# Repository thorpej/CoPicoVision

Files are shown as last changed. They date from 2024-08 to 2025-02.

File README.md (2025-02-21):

# CoPicoVision - A ColecoVision clone using a Raspberry Pi Pico with pico9918 for video
The CoPicoVision stems from yet another bout of nostalgia for a time before
photorealistic video games, when all we had was blocky tile graphics and a
few bleeps and bloops and gosh darn it, we liked it!  When I was a kid, I got
a ColecoVision one Christmas and I played the h*ll out of it.  Alas, I no
longer have it, but I wish I still did, and building a clone seems a lot more
fun than over-paying for one on eBay.

Ok, fine, I have a second motive: It also serves as a test mule for using
modified variants of Troy Schrapel's excellent
[pico9918](https://github.com/visrealm/pico9918) project, something I'm
considering using in other projects, and test mules that can play Mr. Do!
and Zaxxon (yes, yes, yes, and Donkey Kong) are the best kinds of test mules.

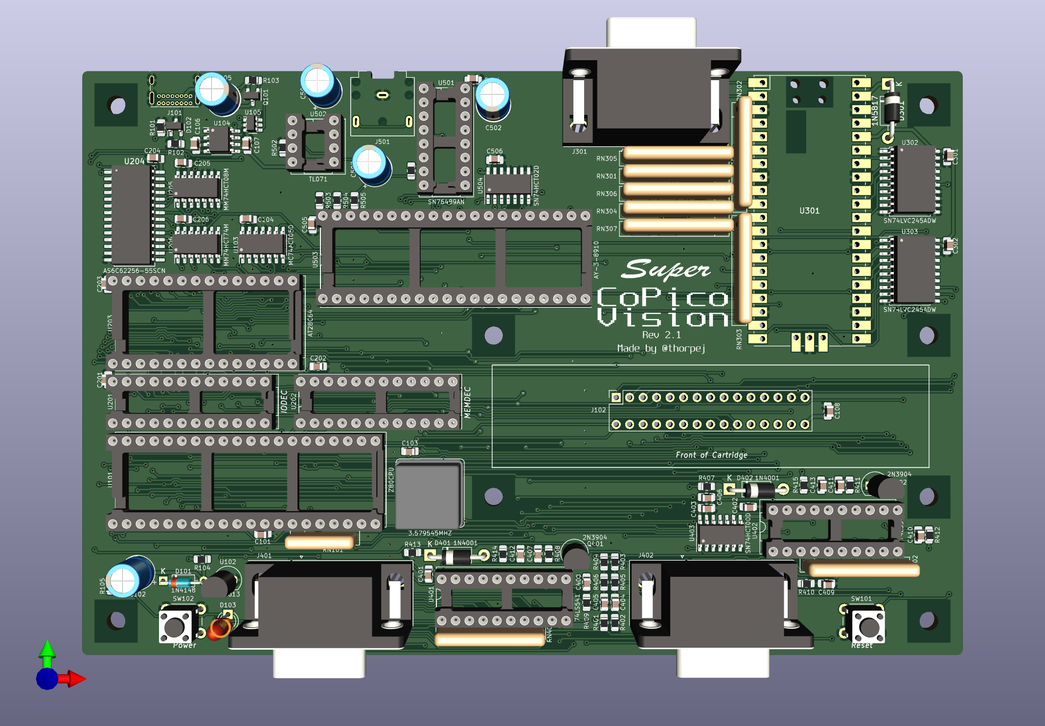
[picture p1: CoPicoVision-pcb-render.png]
3D render of board image


This work is licensed under the [Creative Commons Attribution
ShareAlike 4.0 International license](https://creativecommons.org/licenses/by-sa/4.0/).



## Project Status
### Update - Feb 21, 2025
I've had some time recently to test my one built-up rev 2.0 board (with
all of the necessary rework performed).  I found that one rework procedure
was incomplete, and therefore I'm recommending that others do not build up
any 2.x boards at this time.  I managed to spot the problem and avoided
damaging any chips, but I'd rather be safe than sorry.  I also discovered
another bug, of sorts, in the memory decoding logic when testing an SGM
game ("1942").  Spoiler alert: SGM games are not working correctly yet.
The issue revolves around the way address lines A10-A12 are gated to
provide the stock ColecoVision RAM "mirroring" behavior.  Those lines are
gated too aggressively, and a change to the MEMDEC GAL and a change to
the input signal to the 74HCT08 that gates those lines was required.  I
discovered this using a memory map test utility I wrote for this purpose.
I still don't understand how this bug would break "1942", though, so I
still have some work to do.

### Update - Jan 23, 2025
I received the rev 2.0 boards a little while ago, and the other night started
building one up, only to realize I forgot to oder some parts.  Oh well,
no big deal... I have some travel planned for the next few days, and when
I get back, the parts will be here.  I'm continuing to make tweaks to the
rev 3.0 board, replacing through-hole components with surface-mount
equivalents; it's really amazing how much faster it is to build up a
board with surface-mount bits.  The rev 2.0 CoPicoVision is by far my
most ambitious SMT project to date, and rev 3.0 will be even MOAR.

I've settled on rev 3.0 being the final "classic" CoPicoVision (barring
bugs, obviously), but I am already thinking about a rev 4.0 that will
eliminate the out-of-production audio chips in favor of a second Pi Pico
that will emulate both the SN76489AN and the AY-3-8910.  I'm going to
spend a lot of time breadboarding that before I make the leap, but it's
my goal to eliminate those hard to source parts.  Only the Z80A will remain,
and it's still somewhat available (for now, at least).

### Update - Jan 7, 2025
I've done some work to update to the latest version of pico9918, and
submitted a PR for my build parameterization changes.

### Update - Dec 31, 2024
Ok, I am tagging rev 2.1 that contains the MEMDEC fix and has a rework
procedure involving an interposer board for the AY-3-8910 clock issue.
I don't plan to actually spin any of these boards myself, but it's a
checkpoint (and I am spinning a run of interposers).

Happy New Year, everyone!

### Update - Dec 30, 2024
Aaaaand I've realized I made another error, this time in the SGM extended
memory support.  Specifically, when disabling the BIOS ROM.  I foolishly
used /WR as an input signal to the decoder, completely forgetting the
fact that the Z80 memory cycle timings are very different from the I/O
cycle timings.  To fix this, I'm going to need to change the MEMDEC GAL
inputs and equations (it should take /RD as an input rather than /WR).
I will post a re-work for the rev 2.0 boards (it will involve cutting a
trace and running a short bodge wire between the Z80 and the MEMDEC GAL).

### Update - Dec 29, 2024
I've realized that I made a major error in the clock frequency for the
AY-3-8910, and this is going to require me to spin the board.  Basically,
I used the CPUCLK as the input to the AY-3-8910, when it actually needs
to be divided by 2.  I can do that by adding a D-FF.  I'll make an
interposer board for rev 2.0 systems that sits between the AY-3-8910
and the main board that carries the FF chip.  If that works out OK,
I'll just probably put that down on the main board in rev 3.0, rather
than overhauling the whole clock circuit.

### Update - Dec 21, 2024
Ok, I think I'm going to tag a 2.0 pre-release and get the boards off to
fabrication.  I don't really anticipate making any more board changes in
the short term -- just hanges to ancillary documents.  So stay tuned for
that!

### Update - Dec 19, 2024
Well, I had some time to kill on a plane, so I started the process to
claw back board real estate in order to fit the additional components
needed for "Super CoPicoVision".  But of course, once the initial shrink
was done, I needed to know where the additional components would fit before
I re-routed the board.  This of course meant that I needed to actually
add these additional components to the board, meaning that I needed to do
the work to add them to the schematic.  Anyway, you can probably guess
where this is going!  I need to now fix up the BOM (when you're ordering
ICs in surface-mount packages, you need to be a little more specific about
which part number you order!)

### Update - Dec 15, 2024
I had to take a break from CoPicoVision for a little while for various
reasons, but I'm trying to get back to it.  After mulling it over and
thinking about future "Super CoPicoVision" plans, I decided to change the
audio output buffer to a TL071 opamp, taking advantage of the -5V rail I
have at my disposal.  I added an LTspice simulation of the circuit, including
passively mixing in the output of an AY-3-8910, which would be present on
this hypothetical "Super CoPicoVision".  I want to get this send off to the
fab soon and if everthing is fine, call this version "CoPicoVision 1.0".

I do plan to keep working on it, though!  I plan on experimenting with
the layout, switching to SMT components as necessary, to see if I can fit
the extra chips needed for the Super flavor within the same board footprint.

### Update - Nov 10, 2024
I finally got a chance to get set up with some powered speakers (with a
volume control) to get a better sense of how the audio section behaves.
With the AudioEngine 2+ speakers I tested with, the noise isn't really
that bad at all, and it definitely seems to be a property of the SN76489AN
(placing my finger on top of the chip while running makes an audible
different in the noise profile).

I haven't yet bodged the audio section changes in revision 0.2 onto this
revision 0.1 board.  I really should try to do that soon and re-evaluate.

### Update - Oct 12, 2024
I've updated the schematic and PCB to fix the swapped controller bug in
the rev 0.1 boards, and bumped the revision to 0.2.

I've also built up the audio section of the board and confirmed that it
works.  It's not ideal, though:
* The footprint for the resistor in the emitter-follower is wrong, so even
the relatively-small 1/2 watt resistor I spec'd doesn't quite fit.
* I should have put a current-limiting resistor between the SN76489AN and
the emitter-follower.  It works as it is, but the current setup has the
SN76489AN sourcing more current than it really ought to.  (Maybe I should
have just used a 2N7000 in a source-follower configuration instead?)
* The output is pretty noisy.  It's not _distorted_, but there's hiss and
other audio artifacts.  I remember the original ColecoVision being this
way, but always assumed it was the fault of the RF modulator.  I may bodge
in a passive low-pass filter to cut down on the noise.

### Update - Oct 11, 2024
Built up the controller section and played some Donkey Kong!  I did make
a mistake on the controller section, however.  Controller 1 and 2 are
swapped.  I will correct this in the next revision of the board, and there
is a [procedure](errata/rev0_1_controller_bodge.md) to fix the rev 0.1 boards
that I've already run off.

There also a mistake in the physical placement of the card edge connector
for the cartridge.  It's a few millimeters too close to the front of the
board, and so the cartridge bumps into one of the 2N3904s in the controller
circuit and the cartridge doesn't quite align with the silk screen outline.
That's going to be a little tricker to fix because I might have to re-route
some of the board, but I'll fix that up as well.

Guess I should build the audio section next!

### Update - Oct 10, 2024
After replacing a bad oscillator, the first test board is working!  I have
not yet installed the audio or controller circuitry yet, but I can boot up
Donkey Kong and Buck Rogers, and, due to the lack of controller circuitry
being misinterpreted as input, game play starts!

### Update - Sept 24, 2024
Boards have been back for a while now, and I finally got around to starting
to build one up.  Thought I had all of the resistors I needed in my inventory,
but alas, I did not, so need to place a Jameco order!

### Update - Sept 2, 2024
I made some small adjustments to the PCB, and sent rev 0.1 off for
fabrication!

### Update - Sept 1, 2024
I made forks of pico9918 and vrEmuTms9918 in order to make the changes
needed for CoPicoVision, and then went ahead and made all of those
changes.  Initial firmware version checked in!

### Initial - Aug 31, 2024
The initial "rev 0.1" hardware design is done and ready to send off for
fabrication.  There is some software work to do on the pico9918 side of
things, but the changes I have in mind are trivial.  My plan is to wrap
my changes in proper configuration options and feed those changes back
to Troy.

So, yah, it's early!  Watch this space!

## Design philosophy
My initial goal was to play ColecoVision games (and subsequently, also
games that require the Super Game Module), not to produce a faithful
clone of the circuit.  It needs to be fully-compatible with ColecoVision
and SGM games, but that's the extent of it.  As such, some shortcuts are
going to be taken.

First of all, I'm using Troy Schrapel's excellent pico9918 engine for the video
display.  This reduces the number of vintage parts that need to be sourced, and
gives me VGA video output.  I won't be using the pico9918 as-is, however; since
I don't need all of the outputs of a real TMS9918A (no CPUCLK or GROMCLK), I'm
using a modified pico9918 firmware that doesn't bother with those outputs and
thus allows me to use a regular Raspberry Pi Pico as a module.

Second of all, I'm not going to bother with the expansion interface; I don't
particularly care about connecting an Adam module, and if I ever do, then it
will be time to re-evaluate my life choices.

And lastly, as should be obvious through my use of a microcontroller that's
hundreds of times more powerful than the ColecoVision itself, I have no qualms
about using programmable logic to reduce the part count and generally simplify
the design.  In particular, this means GAL22V10s for address decoding and other
glue logic rather than general-purpuse 7400-series parts.  Atmel still makes
a compatible part, and there are open source tools for programming them, so the
design is still very accessible.

There are three "vintage" parts that are required for the CoPicoVision:
* A 4MHz-capable Z80 CPU in a DIP-40 package.
* A TI SN76489AN sound chip.
* A General Instrument AY-3-8910 sound chip (a Yamaha YM2149 will probably
  also work, but I don't have any to try).  This is only needed if you want
  to be able to play SGM games; regular ColecoVision games will work without
  it.

Eventually, I'd like to replace the SN76489AN and AY-3-8910s with emulated
parts, (almost certainly using a Pi Pico), but for now the real thing needs
to be sourced.

Obviously, with the Z80 now being EOL'd, that poses a bit of a snag.  Luckily,
I have a stash of modern CMOS Z80s, and this design will also accept a vintage
NMOS Z80.  The CPU is clocked at 3.57MHz, so a Z80A or better is necessary.
Maybe one day I'll evaluate one of the FPGA Z80 cores floating around
to see if it's feasible to use one of those with an iCE40 FPGA in an updated
version of the CoPicoVision.  But for now, a genuine Z80 must be used.

## Design details
I spent some time mulling over how I wanted to approach this board.  I
considered doing an all-SMT board (except for the stuff that was only
available as through-hole), but for the first version of the board I
ultimately went with mostly through-hole parts (except for the power supply)
in order to try and keep a more retro look.

This wasn't feasible for version 2, the "Super CoPicoVision"; I wanted to
keep the same basic envelope, so I had no choice to shrink the components
in order to make space for the additional logic chips and the large DIP-40
AY-3-8910.  So, I converted all of the individual resistors and ceramic
capacitors to 0805 packages, and the RAM and most logic ICs to SOIC packages
(I left the 74LS541s in the controller input section as DIP packages).

The board is 4 layers: signals (and ground fill) top and bottom, along with
an internal ground plane and power plane.  I arrived at the size of the board
through experimentation; essentially, I did a rough layout of the board into
what I thought "looked pretty good", placed mounting holes and keep-outs, and
then drew an edge-cut box around it.  Once the box was drawn, I tried to stay
within that envelope.  I'm a total novice when I comes to PCB layout and
design, and I routed the entire board by hand, but did manage to make it fit.
Some signals are routed, ahem, interestingly, but this isn't a high-speed
design so it should be just fine.

The font of the board has power and reset buttons and the 2 controller
ports.  The rear of the board has power, audio, and VGA jacks, along with
the USB connector for the Raspberry Pi Pico in case there's a need to
update the pico9918 firmware.  There's a diode in between the Pico and
the rest of the board, so it's safe to update the firmware in situ.

I've included a bill of materials with Mouser part numbers for just about
everything, including the jellybean SMT resistors / capacitors in standard
0805 packages; these jellybean parts can be substituted with equivalent stock
you might have on hand, of course, but I included Mouser part numbers for
convenience.  For the DIP chip sockets, you whatever kind you prefer.  For
the push button switches, there are lots of garden-variety 6mm through-hole
momentary push buttons out there, so you whatever you prefer.

### Power supply
The power supply is fairly simple, since we don't need the -12V rail that's
found on the original ColecoVision.  We do, however, require a -5V rail, which
is used as a bias voltage in the controller interface circuit as well as for
the op-amp used as an output buffer in the audio circuit.

Power comes in via a USB-C connector (with ESD protection diodes on the
control channel signals).  Power is switched using a MAX16054 on/off
supervisor chip that controls a high-side P-FET to supply power to the
rest of the system.  The MAX16054 is controlled using a single momentary
pushbutton.

The -5V rail is generated using an ICL7660A charge pump chip.

### Clock and reset generation
On the first revision of the CoPicoVision, the clock circuit was as simple
as it gets: a simply a 3.579545 MHz DIP-8 oscillator can that drove the
whole thing, providing CPUCLK signal to the Z80, the M1 wait-state generator,
and the SN76489AN sound chip.

When the Super Game Module enhancements were added in rev 2.0, this clock
was also provided to the AY-3-8190 sound chip, which was actually a mistake
on my part, and it required an annoying work-around to divide CPUCLK by 2
for the AY-3-8190.

So, in rev 3.0, the clock circuit was completely overhauled to use a
14.31818 MHz oscillator to generate the base clock, which is fed into a
74HCT161 binary counter that is used to divide the base frequency by 4
(CPUCLK - 3.579545 MHz) and 8 (AYCLK - 1.789773 MHz).

The reset circuit is based on the DS1813 reset generator IC, which also
de-bounces the reset button.  There is a small RC network that makes the
power-on-reset slightly longer than a manual reset.

### Address decoding and memory
Address decoding is performed using 2 GAL22V10 programmable logic devices.
The original ColecoVision uses 2 74LS138s for address decoding, but also
requires some extra logic to invert some of the signals used by the decoders.
By using GALs for this purpose, I save the extra logic chips.

The ColecoVision also uses a 74LS74 dual D-type flip-flop along with some
additional logic gates to add a wait-state when the Z80 performs an opcode
fetch.  It does this presumably to give some extra breathing room to slow
ROMs (of the Z80 machine cycles, M1 has the tightest timing).  There is
plenty of space in the MEMDEC GAL for this, so that's where I put it.
There is a large comment in the [MEMDEC GAL](gal-files/memdec.gal) source
file that explains how the wait-state generator works.

The BIOS ROM for the CoPicoVision is contained in a 150ns 28C64 EEPROM.
I chose this part because:
* I had a bunch of them on-hand.
* They're totally fast enough.
* They're still being made and you can buy them new from Mouser and DigiKey.

The CoPicoVision's RAM is an AS6C62256-55SCN, which is a 32KB 55ns SRAM chip.

The ColecoVision's memory address space is divided into 8 8KB "pages":

* $0000 - BIOS ROM
* $2000 - Expansion
* $4000 - Expansion
* $6000 - RAM
* $8000 - Cartridge selector 0
* $A000 - Cartridge selector 1
* $C000 - Cartridge selector 2
* $E000 - Cartridge selector 3

The ColecoVision only has 1KB of RAM at $6000, and the addresses are
incompletely decoded, so that 1KB is mirrored throughout that page.

The Super Game Module has 32KB of extended RAM, only 24KB of which is
available unless the BIOS ROM is diabled.  These features are controlled
by the following two registers:

* Writing 0b00000001 to port $53 enables extended RAM.
* Writing 0b00001101 to port $7F disables the BIOS ROM (0b00001111
  re-enables it).  Games must write one of these two values in order
  to maintain compatability with the Adam.

The CoPicoVision uses a 74HCT74 dual D-type flip-flop to provide these two
control registers (only 2 independently-settable bits are needed).  FF1 is
connected to D0 and provides the XRAMEN signal, and FF2 is connected to D1
and provides the ROMEN signal.  The /RESET line is connected such that FF0
is cleared at reset and FF1 is set at reset.  These two signals are used
by the MEMDEC GAL when decoding memory addresses.  A 74HCT08 quad-AND chip
mixes the XRAM signal with RAM address lines A10-A12, forcing them to 0 when
XRAMEN is disabled and passing them through from the CPU when XRAMEN is
enabled, thus maintaining the RAM mirroring behavior of the original
ColecoVision.

When the ROM is enabled, MEMDEC sends reads from the $0000 page to
the ROM, and when disabled it sends those reads to the RAM.  Writes to
the $0000 page are always sent to RAM.  On the CoPicoVision, the $0000 page
RAM behavior is governed entirely by the ROMEN signal.  I suspect this
doesn't exactly match the original Super Game Module behavior, but I also
suspect that it doesn't matter in any practical sense.

I/O address decoding is handled by the [IODEC GAL](gal-files/iodec.gal).
In the original ColecoVision, I/O addresses were incompletely decoded using
address lines A5-A7:

* $8x writes set controller number pad scan mode
* $Ax reads read from the VDP registers
* $Ax writes write to the VDP registers
* $Cx writes set controller joystick scan mode
* $Ex reads read the controllers
* $Ex writes write to the SN76489AN sound chip

To support the SGM extensions, the IODEC GAL also needs to completely
decode the following addresses:

* $50 (AY-3-8910 address latch)
* $51 (AY-3-8910 write data)
* $52 (AY-3-8910 read data)
* $53 writes (extended memory enable register)
* $7F writes (ROM disable register)

A pair of NOR gates from a 74HCT02 are used in conjunction with the /AYSEL
output from IODEC, the A0 address line, and the Z80's /WR signal to generate
the BC1 and BDIR signals used to interface with the AY-3-8910.

### Audio
The audio section is comprised of the two sound chips, whose outputs are
passively mixed using 1K series resistors and then AC-coupled to a TL071
op-amp which serves as an output buffer.  The op-amp's output is then
AC-coupled to both outputs of a 3.5mm TRS phone jack.

### Video
Of course, the video circuit is built using a Raspberry Pi Pico running a
modified version of the pico9918 firmware.  The following changes from
the base pico9918 have been made:
* I don't need the CPUCLK and GROMCLK outputs, so these have been omitted.
This saves 2 pins and means I can use a regular Raspberry Pi Pico.
* I have inverted the interrupt output so that I can use it to drive a
TTL-level open-drain inverter to pull down the Z80's /NMI signal.

The bus interface to the Pico is a little simpler than that used on the
pico9918.  Two 74LVC245 bus transceivers are used to perform the 3V3 <--> 5V
level shift.  This works perfectly fine since I've arranged for everything
on the 5V side to use TTL logic levels, which can accept the 3V3 CMOS logic
level outputs.  One transceiver is hard-wired for the B->A direction and
level-shifts the A0, /VDPWSEL, /VDPRSEL, and /RESET input signals to the Pico.
The other transceiver level-shifts the data bus and takes care of swizzling
the bit order between the VDP and the Z80.  The IODEC GAL generates an extra
signal that's used to enable the output of the data bus transceiver, and the
direction of the transceiver is controlled by /VDPWSEL.

The VGA resistor DAC is identical to the pico9918's.

### Controller interface
The controller interface is derived more or less straight from the
ColecoVision, except the quad-NAND gate is replaced with a 74HCT part.
The controller input buffers are the same 74LS541 used on the original
because the circuit relies on Schmitt trigger inputs and the standard
CMOS replacement parts don't have them.  Eventually I may experiment with
the 74HCS541 as a replacement.

One difference is that I made both controller inputs indentical; in the
original, it seems that one controller input was drawn in a "mirror image"
and the bit order on it's buffer swapped to compensate.  That seemed
needlessly confusing to me, so I just made them both the same (I literally
copy-and-pasted, and then tweaked some net labels to make the second
instance).

The controller interface is by far the most complicated block on the system.
I have a basic understanding of how it works, but there is clearly some subtle
analog magic going on, so I decided not to push my luck.  I don't have any
of the quadrature controllers to test with at this time.

## Errata
Rev 2.x of the CoPicoVision has the following bugs:
* Address lines A10-A12 of the RAM are gated by XRAMEN, which causes
problems when copying the BIOS ROM to the RAM below when extended RAM
is not yet enabled.  This is correct in rev 3.0 of the CoPicoVision board
by adding a new signal, XRAMAD, to the MEMDEC GAL, and using it to gate
those RAM address lines.  XRAMAD is high *unless* the base RAM page is
accessed when extended RAM is disabled, thus preserving the original
ColecoVision "mirroring" behavior.  No re-work procedure for 2.x boards
is provided.

Rev 2.0 of the CoPicoVision has the following bugs:
* The memory address decoder keys off the wrong signal when detecting
reads vs. writes to the 8K page where the BIOS ROM is located.  This can
lead to unreliable behavior when the BIOS ROM is disabled.  This issue only
affects Super Game Module games that disable the BIOS ROM.
[This procedure](errata/rev2_0_memdec_bodge.md) will correct the problem.
The issue is corrected in rev 2.1 of the CoPicoVision board.
**Note: this rework procedure is incomplete.  It is recommended that,
unless you are willing and able to troubleshoot and repair your own board,
that you do not build any rev 2.x boards.**
* The AY-3-8910 sound chip has the wrong clock source.  This will lead to
incorrect sound output of any Super Game Module game that uses the
AY-3-8910 sound chip (which is nearly all of them).  For rev 2.x boards, this
issue is fixed using an interposer board for the AY-3-8910 that also contains
a 74HCT74 D-type flip-flip, which is used to divide the input clock to the
correct frequency.  [This procedure](errata/rev2_x_ay_interposer.md) describes
the procedure for building and installing the interposer board.  This issue
will be corrected in rev 3.0 of the CoPicoVision board, which will have a
completely re-worked clock circuit.

Rev 0.1 of the CoPicoVision has the following bugs:
* Controller 1 and Controller 2 are swapped due to a silly mistake in
the selection logic.  [This procedure](errata/rev0_1_controller_bodge.md)
will correct the problem, or you can just live with it.
* The card edge connector for the cartridge is about 1.5mm too close to the
front of the board.  This was due to a measurement error.  As a result, the
cartridge does not fit within the silkscreen outline on the PCB and the front
of the cartridge may bump into the back of Q402.  You may need to bend Q402
forward a little in order to get the cartridge to seat properly.  I plan to
adjust this in the next board revision, but it may require rerouting several
signals.

## Changes
### Rev 3.0

* Overhauled the clock circuit to properly provide the two different
clock frequencies required (3.579545 MHz for CPUCLK, which is also used
by the basic ColecoVision sound chip, and 1.789773 MHz for AYCLK, used
by the AY-3-8910 SGM sound chip).  This is achieved by using a
14.31818 MHz oscillator which feeds a 74HCT161 binary counter that
divides the input frequency by 4 and 8.
* Changed U102 from TO-92-3 package to an SOT-23 surface-mount package.
* Changed Q401 and Q402 from TO-92-3 packages to SOT-523 surface-mount
packages.
* Changed the VGA resistor ladder DAC to surface-mount packages.
* Added a new XRAMAD signal to the MEMDEC GAL that is active *unless*
the base RAM page is accessed with extended RAM **disabled**.  The
74HCT08 that gates A10-A12 on the SRAM chip now using XRAMAD rather than
XRAMEN.

### Rev 2.1

* Corrects an issue with the memory address decoder that affects Super
Game Module games that disable the BIOS ROM in order to access RAM the
lower 8KB of the address space.
* Adds a rework procedure using an interposer board for fixing an issue
where the incorrect clock frequency is used with the AY-3-8910.

### Rev 2.0.1

This contains corrections / additions to the Bill of Materials.  There are
no circuit or board changes in this revision.

### Rev 2.0
This is the first revision of the Super CoPicoVision!

* Change all of the individual resistors and capacitors to 0805 SMT packages.
* Change most of the logic ICs and the RAM to SOIC SMT packages.
* Add Super Game Module functionality.
* Fix a silly mistake in the rev 0.1 power supply; put the reservoir cap
  on VCC rather than VBUS.

### Rev 0.2
* Fixed the swapped controller port issue in rev 0.1.
* Reworked the output buffer of the audio circuit to use a TL071 op-amp.
* Rerouted some digital signals further away from the audio output path.
* Moved the cartridge connector towards the rear of the board by 1mm.

## Acknowledgements
First of all, I want to say that I was inspired to take a crack at this by the
Leako project, which you can read about [here](https://www.leadedsolder.com/tag/leako).

Second, huge shout out to ChildOfCv on the AtariAge forums for their fantastic
reverse-engineered [ColecoVision schematics](https://forums.atariage.com/topic/285656-new-colecovision-schematics/).

And finally, massive thanks to Troy for his fantastic [pico9918](https://github.com/visrealm/pico9918).
It's truly what makes the CoPicoVision possible.

If you have any questions about the board, you can reach out to me on
Twitter (*[@thorpej](https://twitter.com/thorpej)*) or Mastodon
(*[@thorpej@mastodon.sdf.org](https://mastodon.sdf.org/@thorpej)*).  You
can also check out my [YouTube channel](https://www.youtube.com/@thorpejsf),
which has this and other retrocomputing related content.

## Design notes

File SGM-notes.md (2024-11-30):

# Notes about the Colecovision Super Game Module by Opcode Games.

There is a pretty good write-up of what the Super Game Module is
[here](https://www.colecovision.dk/sem.htm?refreshed).  These here
are notes about how a future "CoPicoVision-SGM" that includes all
of the SGM functionality might work.

The base ColecoVision has 1K of RAM located at $6000 which is only
partially-decoded (A0-A9 are connected to the 2114s, A13-A15 are
connected to the 74LS138 that does memory address decoding).  The
CoPicoVision mimics this behavior -- only A0-A9 are connected to
the 6C6264 SRAM; the upper 7KB are unused.

The SGM allows for up to 32KB of RAM.  When enabled, $2000 - $7FFF
map to RAM, which astute readers will note is 24KB.

The base ColecoVision also maps the ROM into $0000 - $2000.  The SGM
also allows for the ROM to be disabled and this bottom 8KB to be mapped
to RAM, which gives a total of 32KB (the bottom half of the address space
before the cartridge area).

We could easily implement this on the CoPicoVision with a few small
changes:
* Define an XRAMEN signal that, when asserted, enables the extended RAM.
  This signal should default to de-asserted at reset.
* Define a ROMEN signal that, when asserted, enables reading the ROM.
  This signal should default to asserted at reset.
* Replace the 6C6264 with a 6C62256, giving us 32KB of RAM total.
* Changes to the address decoding logic.

Now would the address lines to the 6C2256 be connected and how would the
decoding work?  The CoPicoVision asserts /RAMSEL when A13 and A14 are high
and A15 is low.  Since A13 and A14 are a fixed value when XRAMEN is not
asserted, we don't need to mux those -- they can simply be connected
directly to the RAM chip, and only the lower 1KB of the upper 8KB of the
chip will be used.  A0-A9 can also be connected directly, as they are in
the standard configuration.  We just need to deal with A10-A12.  When
XRAMEN is disabled, we want A10-A12 to be fixed low so that we get the
mirroring behavior of the original circuit.  But when XRAMEN is enabled,
we want A10-A12 to be passed through from the Z80.  This is super easy
to do with just a 74HCT08 quad-AND chip:

       A10 --+
             +-- AND -> RA10
    XRAMEN --+

       A11 --+
             +-- AND -> RA11
    XRAMEN --+

       A12 --+
             +-- AND -> RA12
    XRAMEN --+

Thinking about the ROM and the RAM trapped "beneath" it... it seems like
it would be handy to write to that RAM even when the ROM is enabled.  This
would enable game code to copy the ROM if desired, or let game code otherwise
initialize that RAM before disabling the ROM.  This is pretty easy to do; we
can add the /WR signal as an input to the MEMDEC GAL.  /WR is chosen because
it's used similarly in other parts of the system.

So, how do we want to generate the XRAMEN and ROMEN signals?  In the SGM,
extended RAM is enabled by writing 0b00000001 to port $53.  Because of
the need to maintain Adam compatibility, the SGM has this to say about
disabling the ROM:
* Write 0b00001111 to port $7F to enable the ROM.
* Write 0b00001101 to port $7F to disable the ROM.

Obviously the ROM needs to default to "enabled" at reset.

Also, we're not an Adam, so we don't particularly need all of the bits
in those registers.  I am pretty sure the registers themselves are also
write-only, so there's not even any real need to fully emulate them.

This sounds like a perfect situation for a 74HCT74: dual D-type
positive-edge-triggered flip-flops with Clear and Preset.  Each flip-flop
is completely independent, with its own /CLR and /PRE inputs.  So we
can use them as follows:
* FF1's D input is connected to D0, Q output connected to XRAMEN,
/PRE input connected to Vcc, and /CLR input connected to /RESET.
* FF2's D input is connected to D1, Q output connected to ROMEN,
/PRE input connected to /RESET, and /CLR input connected to Vcc.

Each FF would get a clock input from the IODEC address decoder, call them
/FF1SEL and /FF2SEL for now.

The base CoPicoVision MEMDEC GAL has the following connections:

    CLK M1 /MREQ   /RFSH      A13       A14      A15      NC     NC NC  NC     GND
    NC  NC  M1WAIT /CRTESEL  /CRTCSEL  /CRTASEL /CRT8SEL /RAMSEL NC NC /ROMSEL VCC

We know we need to add /WR, XRAMEN, and ROMEN as inputs.  Unfortunately,
there aren't enough available outputs to use the MEMDEC GAL for A10-A12,
so we'll have to add a 74HCT08 to the board.

So, with that in mind, here's what the new GAL equations for /ROMSEL and
/RAMSEL could look like:

    CLK M1 /MREQ   /RFSH      A13       A14      A15     /WR     XRAMEN ROMEN  NC     GND
    NC  NC  M1WAIT /CRTESEL  /CRTCSEL  /CRTASEL /CRT8SEL /RAMSEL NC     NC    /ROMSEL VCC

    ROMSEL   = /A15 * /A14 * /A13 * MREQ * /RFSH * /WR *  ROMEN ; ROM reads, ROM enabled
    RAMSEL   = /A15 * /A14 * /A13 * MREQ * /RFSH * /WR * /ROMEN ; ROM reads, ROM disabled
             + /A15 * /A14 * /A13 * MREQ * /RFSH *  WR          ; ROM writes
             + /A15 * /A14 *  A13 * MREQ * /RFSH * XRAMEN       ; XRAM $2000
             + /A15 *  A14 * /A13 * MREQ * /RFSH * XRAMEN       ; XRAM $4000
             + /A15 *  A14 *  A13 * MREQ * /RFSH                ; base RAM

Now let's take a look at what we need to change in the I/O address
decoding.  The base CoPicoVision IODEC GAL looks like this:

    /IORQ /WR A5 A6  A7     NC      NC      NC     NC       NC       NC     GND
     NC    NC NC NC /CRSEL /C1WSEL /C2WSEL /VDPEN /VDPWSEL /VDPRSEL /SNWSEL VCC

    C2WSEL  = A7 * /A6 * /A5 * IORQ *  WR		; $80 writes
    VDPRSEL = A7 * /A6 *  A5 * IORQ * /WR		; $A0 reads
    VDPWSEL = A7 * /A6 *  A5 * IORQ *  WR		; $A0 writes
    VDPEN   = A7 * /A6 *  A5 * IORQ			; enable VDP transceiver
    C1WSEL  = A7 *  A6 * /A5 * IORQ *  WR		; $C0 writes
    CRSEL   = A7 *  A6 *  A5 * IORQ * /WR		; $E0 reads
    SNWSEL  = A7 *  A6 *  A5 * IORQ *  WR		; $E0 writes

Because we need to decode $53 and $7F, we're going to need to get all
8 of I/O port address bits connected to the GAL.

We need to generate a positive-edge clock pulse for the extended memory
FF's when they are written.  Looking at the Z80 I/O cycle timing diagram,
we can see that D0-D7 will be valid until the end of T3, and the /WR signal
is de-asserted before the end of T3, so that will do exactly what we need
in order to generate those.  We're also going to decode at least part of
the AY-3-8910 address space, since we have all of the address lines coming
in here as it is (see below for details):

So, with that, it looks like:

    /IORQ /WR     A0       A1       A2     A3      A4      A5     A6       A7       NC     GND
     NC   /AYSEL /FF1WSEL /FF2WSEL /CRSEL /C1WSEL /C2WSEL /VDPEN /VDPWSEL /VDPRSEL /SNWSEL VCC

    AYSEL   = /A7 * A6 * /A5 * A4 * /A3 * /A2 * /A1 * /A0 * IORQ ; $50
            + /A7 * A6 * /A5 * A4 * /A3 * /A2 * /A1 *  A0 * IORQ ; $51
            + /A7 * A6 * /A5 * A4 * /A3 * /A2 *  A1 * /A0 * IORQ ; $52

    FF1WSEL = /A7 * A6 * /A5 * A4 * /A3 * /A2 *  A1 *  A0 * IORQ *  WR ; $53 writes
    FF2WSEL = /A7 * A6 *  A5 * A4 *  A3 *  A2 *  A1 *  A0 * IORQ *  WR ; $7F writes

    C2WSEL  = A7 * /A6 * /A5 * IORQ *  WR		; $80 writes
    VDPRSEL = A7 * /A6 *  A5 * IORQ * /WR		; $A0 reads
    VDPWSEL = A7 * /A6 *  A5 * IORQ *  WR		; $A0 writes
    VDPEN   = A7 * /A6 *  A5 * IORQ			; enable VDP transceiver
    C1WSEL  = A7 *  A6 * /A5 * IORQ *  WR		; $C0 writes
    CRSEL   = A7 *  A6 *  A5 * IORQ * /WR		; $E0 reads
    SNWSEL  = A7 *  A6 *  A5 * IORQ *  WR		; $E0 writes

...which leaves one available output on the IODEC GAL.

OK!  On to the AY-3-8910 PSG!  Looks like the following I/O ports are
used for the PSG:
* $50 (w) -- address latch
* $51 (w) -- write data
* $52 (r) -- read data

This is very similar to what is used on the MSX:
* $A0 (w) -- address latch
* $A1 (w) -- write data
* $A2 (r) -- read data

The AY-3-8910 uses the goofy bus protocol from the General Instrument
CP1600, and so we have to generate the BDIR, BC1, and BC2 signals from
the I/O port accesses.  The AY-3-8910 manual further states that the BC2
signal can be tied to Vcc and that only 4 of the CP1600 bus states are
actually used:
* BDIR=0 BC1=0 -- inactive
* BDIR=0 BC1=1 -- read from PSG
* BDIR=1 BC1=0 -- write to PSG
* BDIR=1 BC1=1 -- latch address

We can achieve this with 2 gates from a 74HCT02 quad-NOR:

          A0 --+
               +-- NOR -> BC1
             +-+
    /AYSEL --+
             +-+
               +-- NOR -> BDIR
         /WR --+

Here's the truth table:

    /AYSEL    /WR    A0        BDIR    BC1
       0       0      0          1      1       <- write to $x0 (addr latch)
       0       0      1          1      0       <- write to $x1 (write data)
       0       1      0          0      1       <- read from $x2 (read data)
       0       1      1          0      0
       1       0      0          0      0
       1       0      1          0      0
       1       1      0          0      0
       1       1      1          0      0

So, what's the part count difference?
* Replace 6C6264 with 6C62256.
* Add 74HCT08.
* Add 74HCT74.
* Add AY-3-8910.
* Add 74HCT02.

...which is 4 additional chips, and one of them is pretty big.  That would
definitely require me to re-think the CoPicoVision board layout.

Now, for mixing the output of the SN and AY sound chips... The original
ColecoVision has a 1.8K series resistor and 0.1uF cap between the SN and
the RF modulator, and the EXAUD goes though a 0.1uF cap before being mixed
in betweem the above resistor and cap.

I'm pretty sure the nominal output voltages are very similar between the
SN and AY chips.  I think just a 1K series resistor after each chip output
to sum them before the output buffer will do fine, but I think I will
breadboard this and experiment with an Arduino or something first.

Ok, I've added a simulation of a possible passive mixing circuit for SGM
audio.  It also eliminates the emitter-follower for the audio outut; it
turns out to seemingly not be necessary, even on the base CoPicoVision.

More thoughts to come...

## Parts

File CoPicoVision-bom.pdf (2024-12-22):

### CoPicoVision rev 2.0 Bill of Materials

Source: | CoPicoVision.kicad_sch
Component Count: | 117
Item | Qty | Reference(s) | Value | LibPart | Footprint | Mouser
1 | 20 | C101, C103, C104, C108, C201, C202, C203, C204, C205, C206, C301, C302, C401, C402, C403, C406, C409, C501, C505, C506 | 0.1µF | Device:C_Small | Capacitor_SMD:C_0805_2012Metric_Pad1.18x1.45mm_HandSolder | 581-KAM21BR71H104JT
2 | 2 | C102, C105 | 100µF | Device:C_Polarized_Small | Capacitor_THT:CP_Radial_D6.3mm_P2.50mm | 710-860040373002
3 | 2 | C106, C107 | 10µF | Device:C_Small | Capacitor_SMD:C_0805_2012Metric_Pad1.18x1.45mm_HandSolder | 80-C0805C106J8RAUTLR
4 | 4 | C404, C405, C412, C413 | 0.01µF | Device:C_Small | Capacitor_SMD:C_0805_2012Metric_Pad1.18x1.45mm_HandSolder | 581-08055C103J
5 | 2 | C407, C411 | 100pF | Device:C_Small | Capacitor_SMD:C_0805_2012Metric_Pad1.18x1.45mm_HandSolder | 581-08055C101JAT2A
6 | 2 | C408, C410 | .047µF | Device:C_Small | Capacitor_SMD:C_0805_2012Metric_Pad1.18x1.45mm_HandSolder | 80-C0805C473J5R
7 | 1 | C502 | 22µF | Device:C_Polarized_Small | Capacitor_THT:CP_Radial_D6.3mm_P2.50mm | 647-RNS1C220MDS1
8 | 2 | C503, C504 | 2.2µF | Device:C_Polarized_Small | Capacitor_THT:CP_Radial_D6.3mm_P2.50mm | 667-ECA-2DM2R2I
9 | 1 | D101 | 1N4148 | Diode:1N4148 | Diode_THT:D_DO-35_SOD27_P7.62mm_Horizontal | 512-1N4148
10 | 1 | D102 | ESDA25L | Power_Protection:SP0502BAHT | Package_TO_SOT_SMD:SOT-23 | 511-ESDA25L
11 | 1 | D103 | Power LED | Device:LED | LED_THT:LED_D3.0mm | 78-TLHK46Q1R2
12 | 1 | D301 | 1N5817 | Diode:1N5817 | Diode_THT:D_DO-41_SOD81_P10.16mm_Horizontal | 511-1N5817
13 | 2 | D401, D402 | 1N4001 | Diode:1N4001 | Diode_THT:D_DO-41_SOD81_P10.16mm_Horizontal | 637-1N4001
14 | 8 | H101, H102, H103, H104, H105, H106, H107, H108 | MountingHole | Mechanical:MountingHole | MountingHole:MountingHole_3.5mm
15 | 1 | J101 | USB_C_Receptacle_PowerOnly_6P | Connector:USB_C_Receptacle_PowerOnly_6P | Connector_USB:USB_C_Receptacle_GCT_USB4085 | 640-USB4085-GF-A
16 | 1 | J102 | Conn_02x15_Odd_Even | Connector_Generic:Conn_02x15_Odd_Even | jrt-Connectors:Sullins_Cart_Slot | 571-5530843-2
17 | 1 | J301 | DE15_Receptacle_HighDensity_MountingHoles | Connector:DE15_Receptacle_HighDensity_MountingHoles | Connector_Dsub:DSUB-15-HD_Female_Horizontal_P2.29x1.98mm_EdgePinOffset8.35mm_Housed_MountingHolesOffset10.89mm | 523-7HDE15SDH4RHNVGA
18 | 1 | J401 | Controller 1 | Connector:DE9_Plug_MountingHoles | Connector_Dsub:DSUB-9_Male_Horizontal_P2.77x2.84mm_EdgePinOffset7.70mm_Housed_MountingHolesOffset9.12mm | 523-G17C0910132EU
19 | 1 | J402 | Controller 2 | Connector:DE9_Plug_MountingHoles | Connector_Dsub:DSUB-9_Male_Horizontal_P2.77x2.84mm_EdgePinOffset7.70mm_Housed_MountingHolesOffset9.12mm | 523-G17C0910132EU
20 | 1 | J501 | AudioJack3 | Connector_Audio:AudioJack3 | Connector_Audio:Jack_3.5mm_CUI_SJ1-3523N_Horizontal | 490-SJ1-3523N
21 | 1 | Q101 | MMFTP3334K-AQ | Device:Q_PMOS_GSD | Package_TO_SOT_SMD:SOT-23 | 637-MMFTP3334K-AQ
22 | 2 | Q401, Q402 | 2N3904 | Transistor_BJT:2N3904 | Package_TO_SOT_THT:TO-92_Inline | 583-2N3904
23 | 2 | R101, R102 | 5K1 | Device:R_Small | Resistor_SMD:R_0805_2012Metric_Pad1.20x1.40mm_HandSolder | 71-CRCW0805-5.1K-E3
24 | 4 | R103, R409, R412, R502 | 10K | Device:R_Small | Resistor_SMD:R_0805_2012Metric_Pad1.20x1.40mm_HandSolder | 71-CRCW0805-10K-E3
25 | 1 | R104 | 3K3 | Device:R_Small | Resistor_SMD:R_0805_2012Metric_Pad1.20x1.40mm_HandSolder | 71-CRCW0805-3.3K-E3
26 | 1 | R105 | 330R | Device:R_Small | Resistor_SMD:R_0805_2012Metric_Pad1.20x1.40mm_HandSolder | 71-CRCW0805-330-E3
27 | 2 | R401, R402 | 220R | Device:R_Small | Resistor_SMD:R_0805_2012Metric_Pad1.20x1.40mm_HandSolder | 71-CRCW0805-220-E3
28 | 3 | R403, R404, R413 | 1.5K | Device:R_Small | Resistor_SMD:R_0805_2012Metric_Pad1.20x1.40mm_HandSolder | 71-CRCW0805-1.5K-E3
29 | 2 | R405, R406 | 120R | Device:R_Small | Resistor_SMD:R_0805_2012Metric_Pad1.20x1.40mm_HandSolder | 71-CRCW0805120RFKEA
30 | 2 | R407, R410 | 1.8K | Device:R_Small | Resistor_SMD:R_0805_2012Metric_Pad1.20x1.40mm_HandSolder | 71-CRCW0805-1.8K-E3
31 | 2 | R408, R411 | 22K | Device:R_Small | Resistor_SMD:R_0805_2012Metric_Pad1.20x1.40mm_HandSolder | 71-CRCW0805-22K-E3
32 | 2 | R414, R415 | 100K | Device:R_Small | Resistor_SMD:R_0805_2012Metric_Pad1.20x1.40mm_HandSolder | 71-CRCW0805-100K-E3
33 | 4 | R501, R503, R504, R505 | 1K | Device:R_Small | Resistor_SMD:R_0805_2012Metric_Pad1.20x1.40mm_HandSolder | 71-CRCW0805-1.0K-E3
34 | 1 | RN101 | 3K3 | Device:R_Network04_Split | Resistor_THT:R_Array_SIP5 | 652-4605M-1LF-3.3K
35 | 7 | RN301, RN302, RN303, RN304, RN305, RN306, RN307 | 1K | Device:R_Pack04_SIP | Resistor_THT:R_Array_SIP8 | 652-4608X-2LF-1K
36 | 2 | RN401, RN402 | 22K | Device:R_Network07 | Resistor_THT:R_Array_SIP8 | 652-4608X-1LF-22K
37 | 2 | SW101, SW102 | SW_Push | Switch:SW_Push | Button_Switch_THT:SW_PUSH_6mm
38 | 1 | U101 | Z80CPU | CPU:Z80CPU | Package_DIP:DIP-40_W15.24mm_Socket
39 | 1 | U102 | DS1813 | jrt-ICs:DS1813 | Package_TO_SOT_THT:TO-92_Inline | 700-DS1813-10T&R
40 | 1 | U103 | MC74ACT05D | 74xx:74LS05 | Package_SO:SOIC-14_3.9x8.7mm_P1.27mm | 863-MC74ACT05DR2G
41 | 1 | U104 | ICL7660A | Regulator_SwitchedCapacitor:ICL7660 | Package_SO:SOIC-8_3.9x4.9mm_P1.27mm | 968-ICL7660AIBAZA
42 | 1 | U105 | MAX16054 | jrt-ICs:MAX16054 | Package_TO_SOT_SMD:SOT-23-6 | 700-MAX16054AZTT
43 | 2 | U201, U202 | GAL22V10 | jrt-ICs:GAL22V10 | Package_DIP:DIP-24_W7.62mm_Socket | 556-AF22V10C15PU
44 | 1 | U203 | AT28C64 | jrt-ICs:AT28C64 | Package_DIP:DIP-28_W15.24mm_Socket | 556-AT28C64B15PU
45 | 1 | U204 | AS6C62256-55SCN | Memory_RAM:CY62256-70PC | Package_SO:SOIC-28W_7.5x18.7mm_P1.27mm | 913-AS6C62256-55SCN
46 | 1 | U205 | MM74HCT08M | 74xx:74LS08 | Package_SO:SOIC-14_3.9x8.7mm_P1.27mm | 512-MM74HCT08MX
47 | 1 | U206 | MM74HCT74M | 74xx:74HC74 | Package_SO:SOIC-14_3.9x8.7mm_P1.27mm | 512-MM74HCT74MX
48 | 1 | U301 | Pico | jrt-RPI_Pico:Pico | jrt-RPI_Pico:RPi_Pico_SMD_TH
49 | 2 | U302, U303 | SN74LVC245ADW | 74xx:74HC245 | Package_SO:SOIC-20W_7.5x12.8mm_P1.27mm | 595-SN74LVC245ADWR
50 | 2 | U401, U402 | 74LS541 | 74xx:74LS541 | Package_DIP:DIP-20_W7.62mm_Socket | 595-SN74LS541NE4
51 | 1 | U403 | SN74HCT00D | 74xx:74HCT00 | Package_SO:SOIC-14_3.9x8.7mm_P1.27mm | 595-SN74HCT00DR
52 | 1 | U501 | SN76489AN | jrt-ICs:SN76489AN | Package_DIP:DIP-16_W7.62mm_Socket
53 | 1 | U502 | TL071 | Amplifier_Operational:TL071 | Package_DIP:DIP-8_W7.62mm_Socket | 595-TL071CP
54 | 1 | U503 | AY-3-8910 | jrt-ICs:AY-3-8910 | Package_DIP:DIP-40_W15.24mm_Socket
55 | 1 | U504 | SN74HCT02D | 74xx:74HCT02 | Package_SO:SOIC-14_3.9x8.7mm_P1.27mm | 595-SN74HCT02DR
56 | 1 | X101 | 3.579545MHZ | Oscillator:CXO_DIP8 | Oscillator:Oscillator_DIP-8 | 520-TCH357-X

1

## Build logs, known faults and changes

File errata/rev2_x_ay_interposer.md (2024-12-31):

# Rev 2.x AY-3-8910 clock fix interposer board

Rev 2.x of the CoPicoVision provides an incorrect clock frequency to the
AY-3-8910 sound chip.  For these CoPicoVision revisions, an interposer
board is used to provide the correct clock frequency to the AY-3-8910.

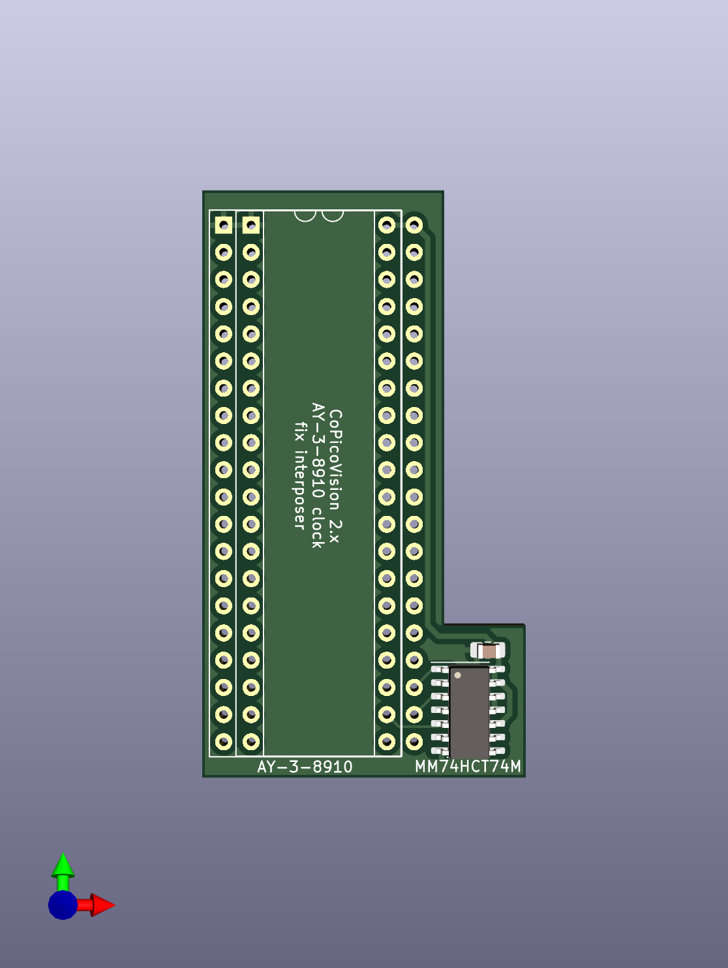
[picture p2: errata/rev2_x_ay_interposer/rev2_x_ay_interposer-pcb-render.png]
AY-3-8910 interposer board


Use [these Gerber files](rev2_x_ay_interposer/Gerbers) to order a run
of interposer board PCBs.  In addition to the PCBs, you will need:

* 2 1x20-pin machined pin male headers with 2.54mm spacing.
* 1 standard DIP-40 socket.
* 1 MM74HCT74M (or equivalent) in surface-mount SOIC-14-Narrow package.
* 1 0.1uF ceramic capacitor in surface-mount 0805 package.

On the top of the board is a DIP-40 socket to hold the AY-3-8910.  Offset
just to the right of the socket pins are machine pin headers facing down
that plug into the AY-3-8910 socket (U503) on the CoPicoVision board.

This simple 6-step procedure is the recommended assembly order for the
interposer board.

## Step 1

Solder the 0.1uF ceramic capacitor onto the footprint directly above
the MM74HCT74M.

## Step 2

Solder the MM74HCT74M to its footprint.

## Step 3

Install the 2 1x20 machined pin headers on the bottom side of the board,
facing downwards.  Of each pair of through-hole columns, the headers are
installed on the right pair (when viewed from the top of the board).  These
pin headers must be soldered from the top of the board, so it is crucial
that they are soldered before proceeding to step 4.

## Step 4

Install the DIP-40 socket on the top side of the board and solder it from
the bottom side of the board.

## Step 5

Remove the AY-3-8910 (U503) from its socket on the CoPicoVision and install
it into the socket on the interposer board.

## Step 6

Install the interposer board into the AY-3-8910 (U503) socket on the
CoPicoVision.

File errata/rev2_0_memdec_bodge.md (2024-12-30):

# Rev 2.0 memory address decoder fix

This simple 5-step procedure will fix the memory address decoder issue
that exists on rev 2.0 boards.

## Step 1

Locate the traces on the back side of the board that connects pin 22
of U101 to pin 6 of U202 and then on to a via.

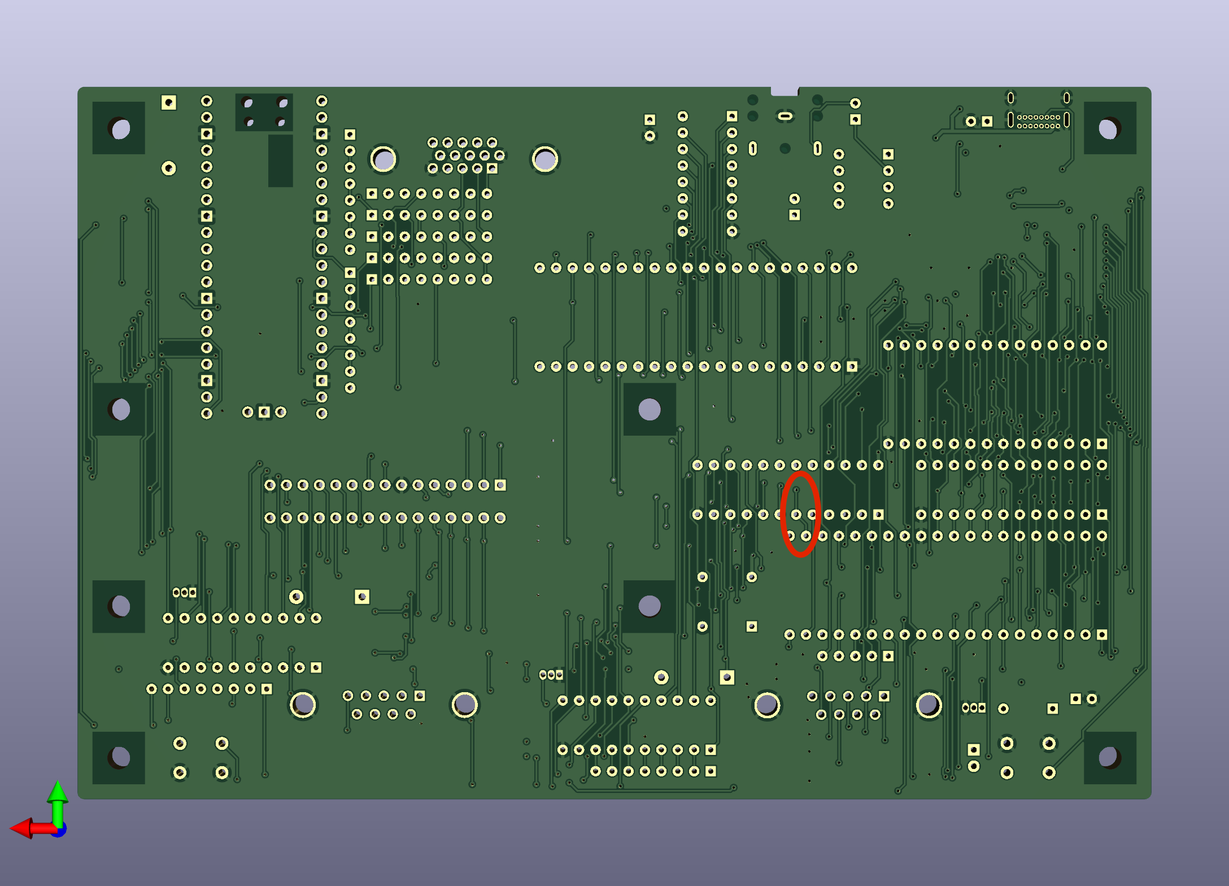
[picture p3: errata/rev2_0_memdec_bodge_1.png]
Locate these trace


Once located, cut the traces.

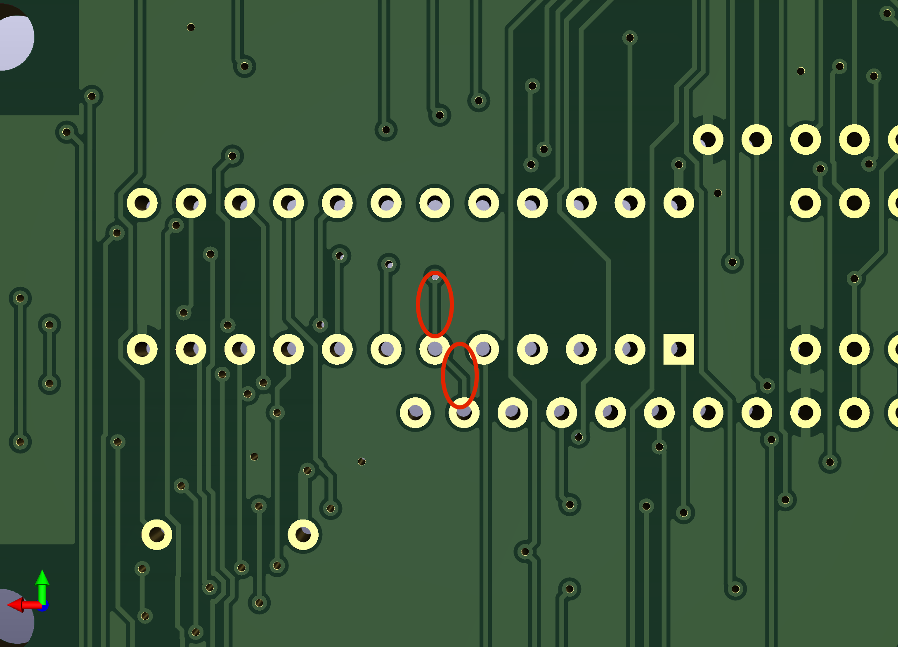
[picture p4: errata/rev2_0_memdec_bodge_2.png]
Cut these traces


## Step 2

Solder a bodge wire to pin 21 of U101 and pin 6 of U202.  Secure the
wire with Kapton tape.

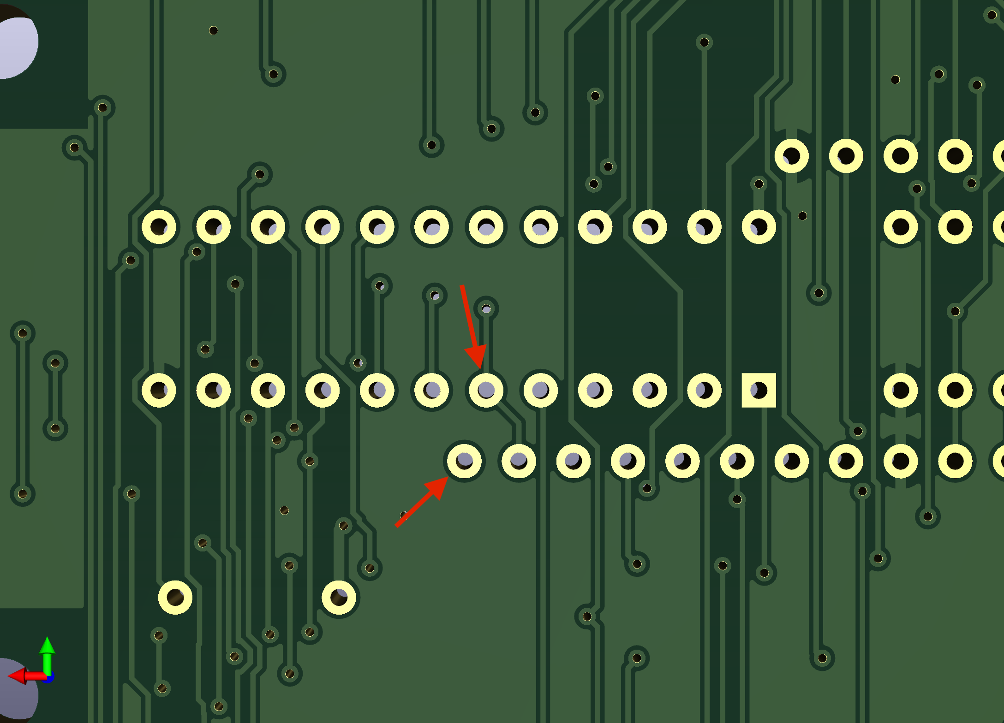
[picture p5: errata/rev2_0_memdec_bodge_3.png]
U101-21 to U202-6


## Step 3

Solder a bodge wire to pin 22 of U101 and pin 2 of U201.  Secure the
wire with Kapton tape.

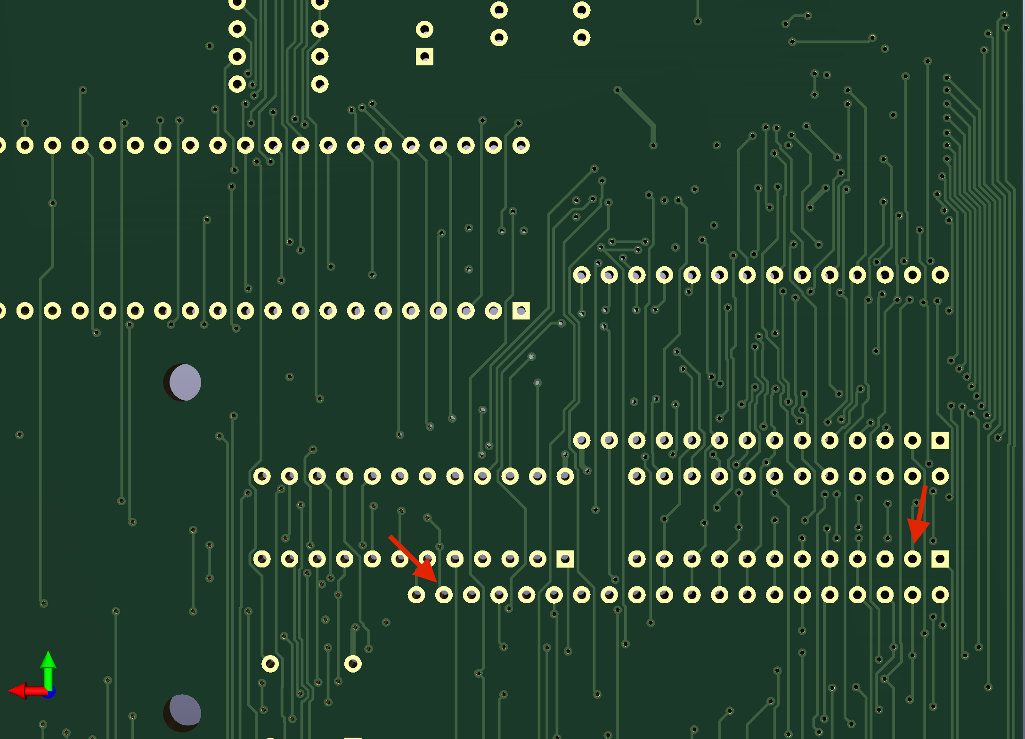
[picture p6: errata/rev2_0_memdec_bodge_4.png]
U101-22 to U201-2


## Step 4

Flip the board over to work on the front side.  Solder a bodge wire to
the leg of pin 27 of U204 and the leg of pin 6 of U504.  Secure the
wire with Kapton tape.

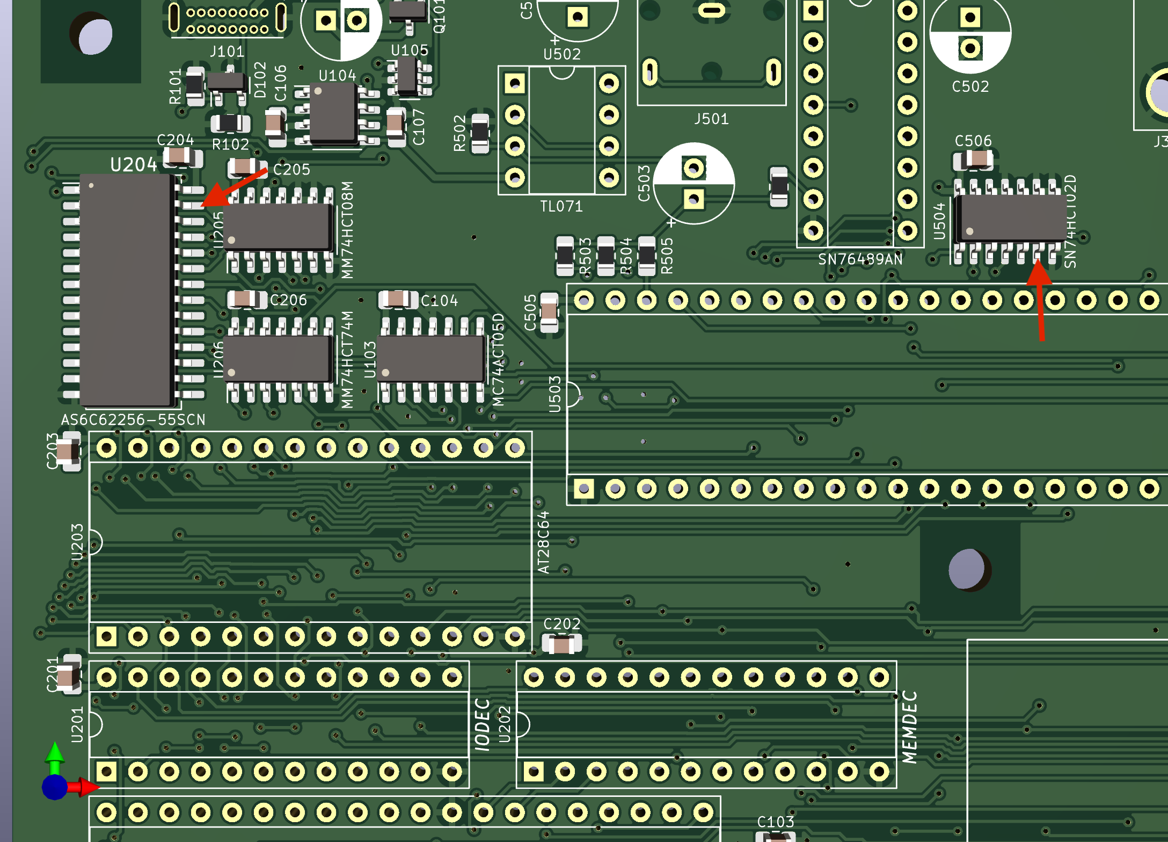
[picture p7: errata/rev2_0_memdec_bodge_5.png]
U204-27 to U504-6


## Step 5

Remove U202 (the MEMDEC GAL) from the socket.  Re-program the GAL using
[this version](../gal-files/memdec.jed) of the MEMDEC fuse map.  Re-insert
the MEMDEC GAL into the socket.

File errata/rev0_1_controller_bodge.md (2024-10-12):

# Rev 0.1 swapped controller fix

This simple 3-step procedure will fix the swapped controller problem that
exists on rev 0.1 boards.

## Step 1

Cut the following two traces on the back side of the board.

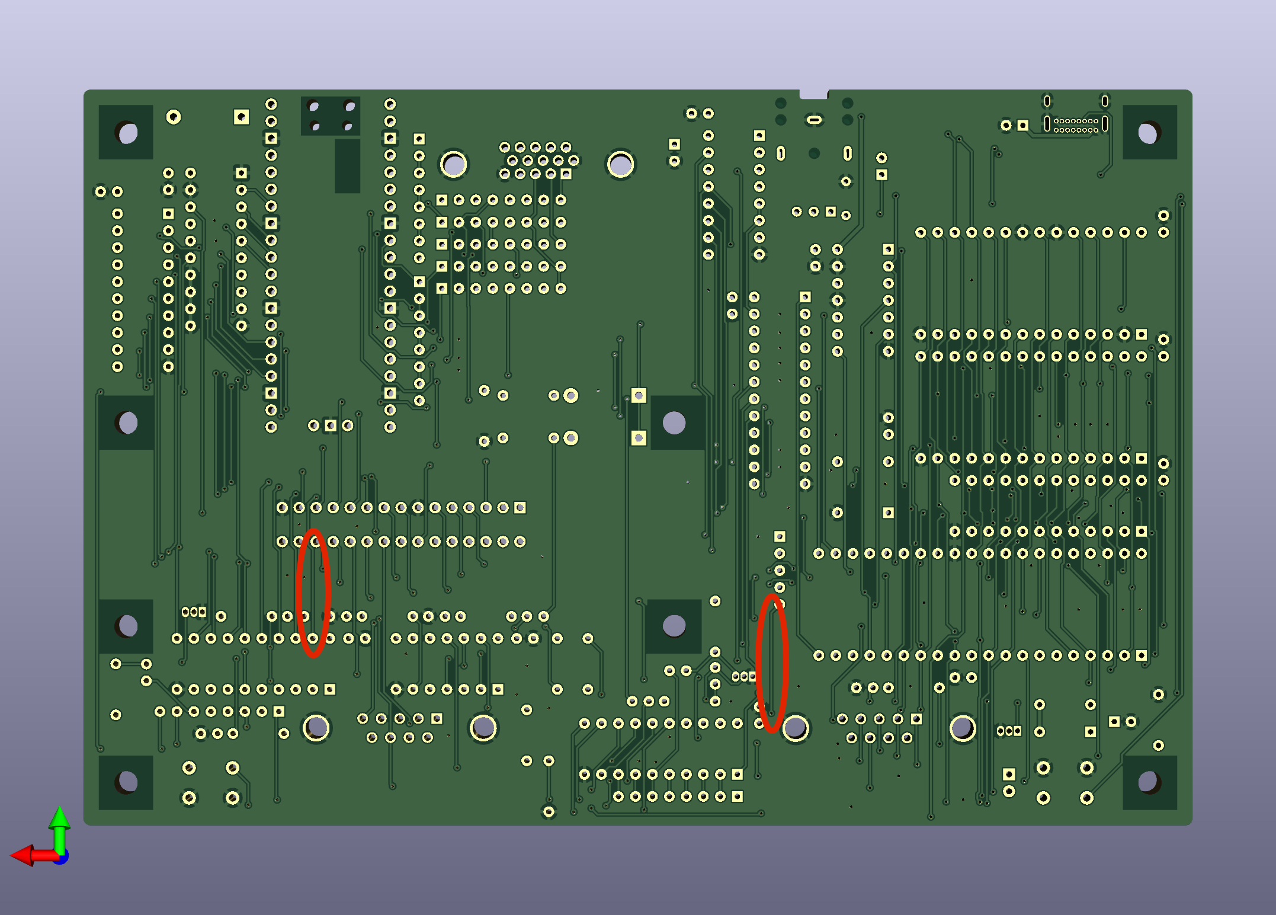
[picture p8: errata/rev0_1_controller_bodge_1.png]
Cut these traces


## Step 2

Solder a bodge wire to pin 5 of RN101 and pin 19 of U402.  Secure the
wire with Kapton tape.

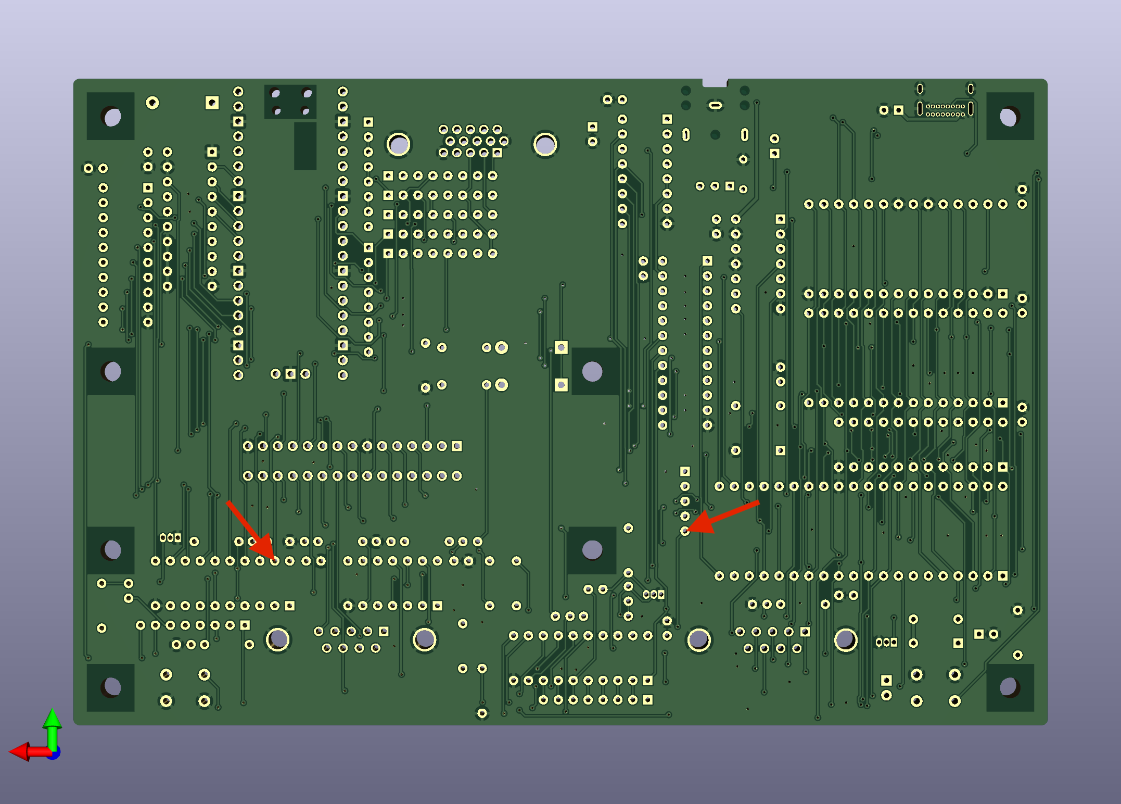
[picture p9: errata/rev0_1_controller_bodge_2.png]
RN101-5 to U402-19


## Step 3

Solder a bodge wire to pin 19 of U401 and pin 31 of U101.  Secure the
wire with Kapton tape.

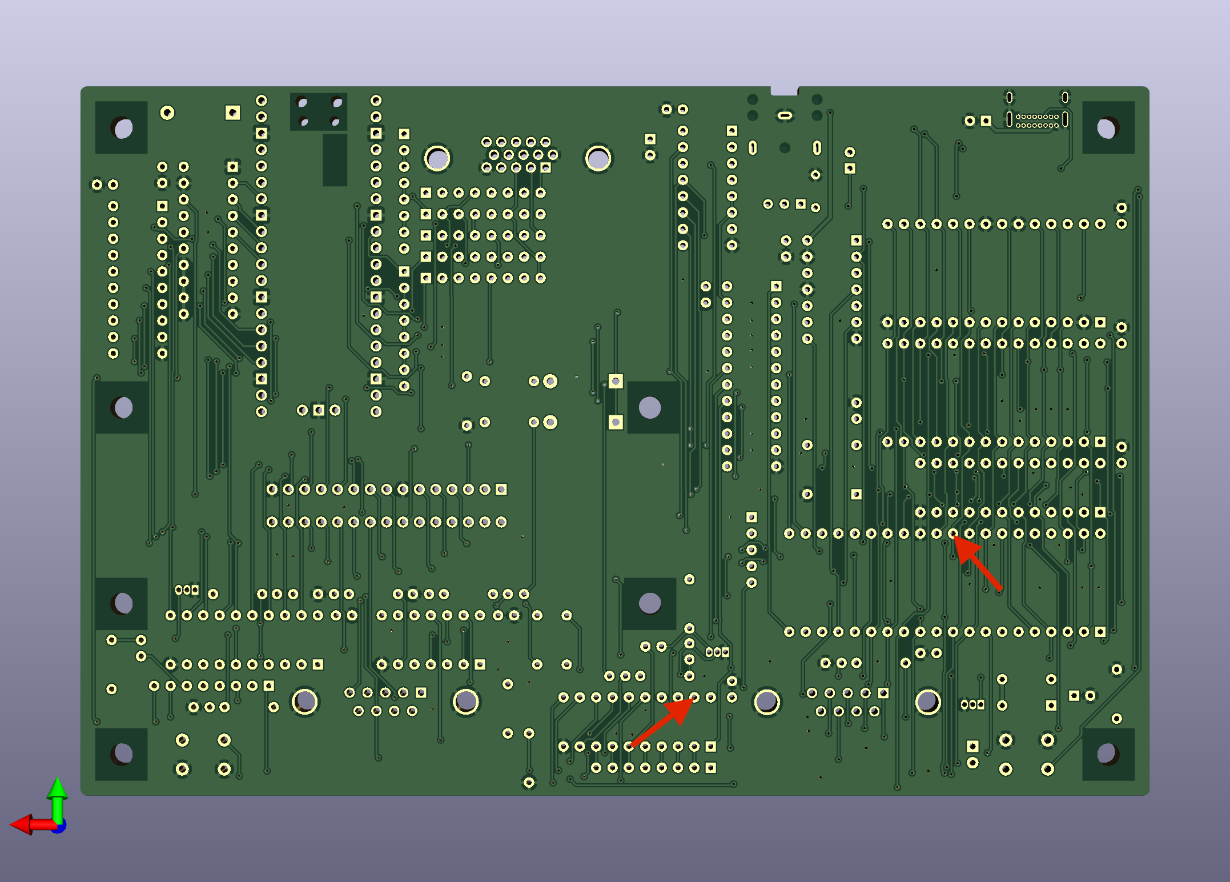
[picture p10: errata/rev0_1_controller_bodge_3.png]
U401-19 to U101-31


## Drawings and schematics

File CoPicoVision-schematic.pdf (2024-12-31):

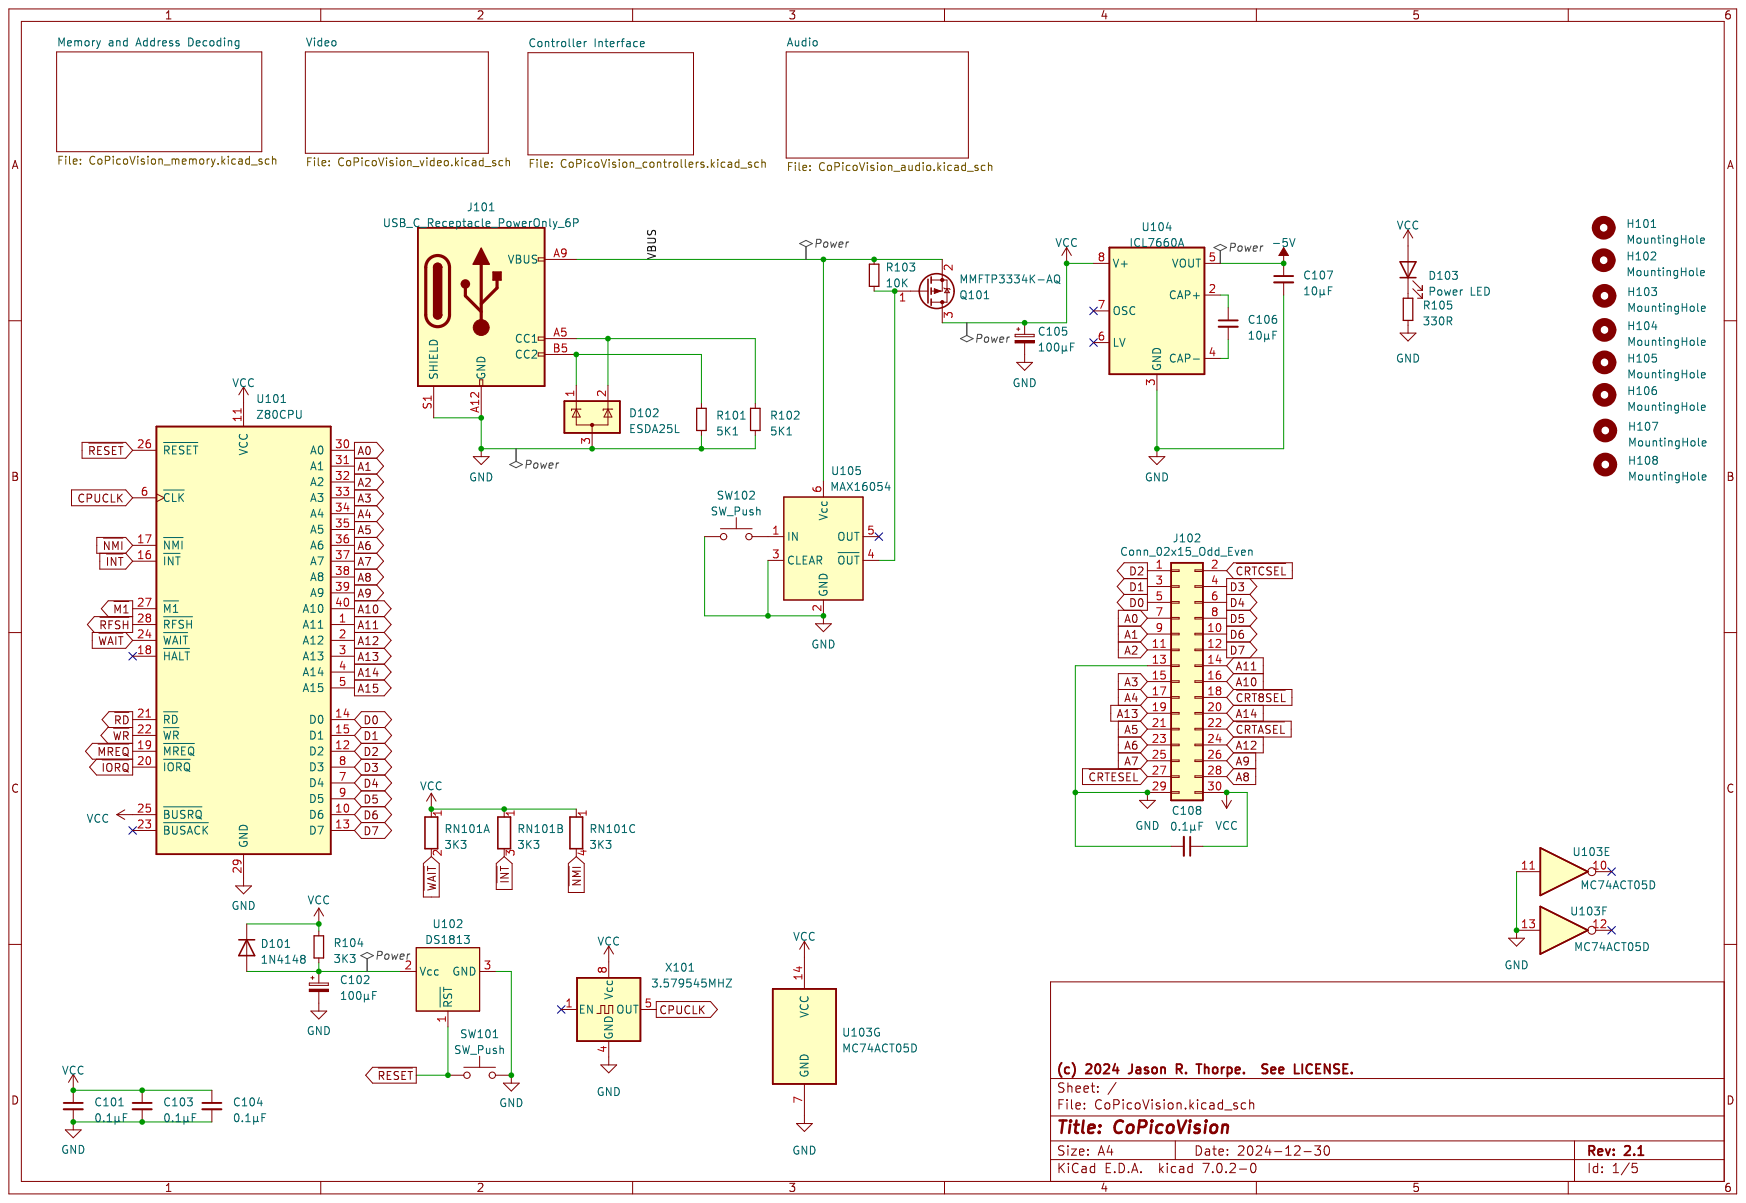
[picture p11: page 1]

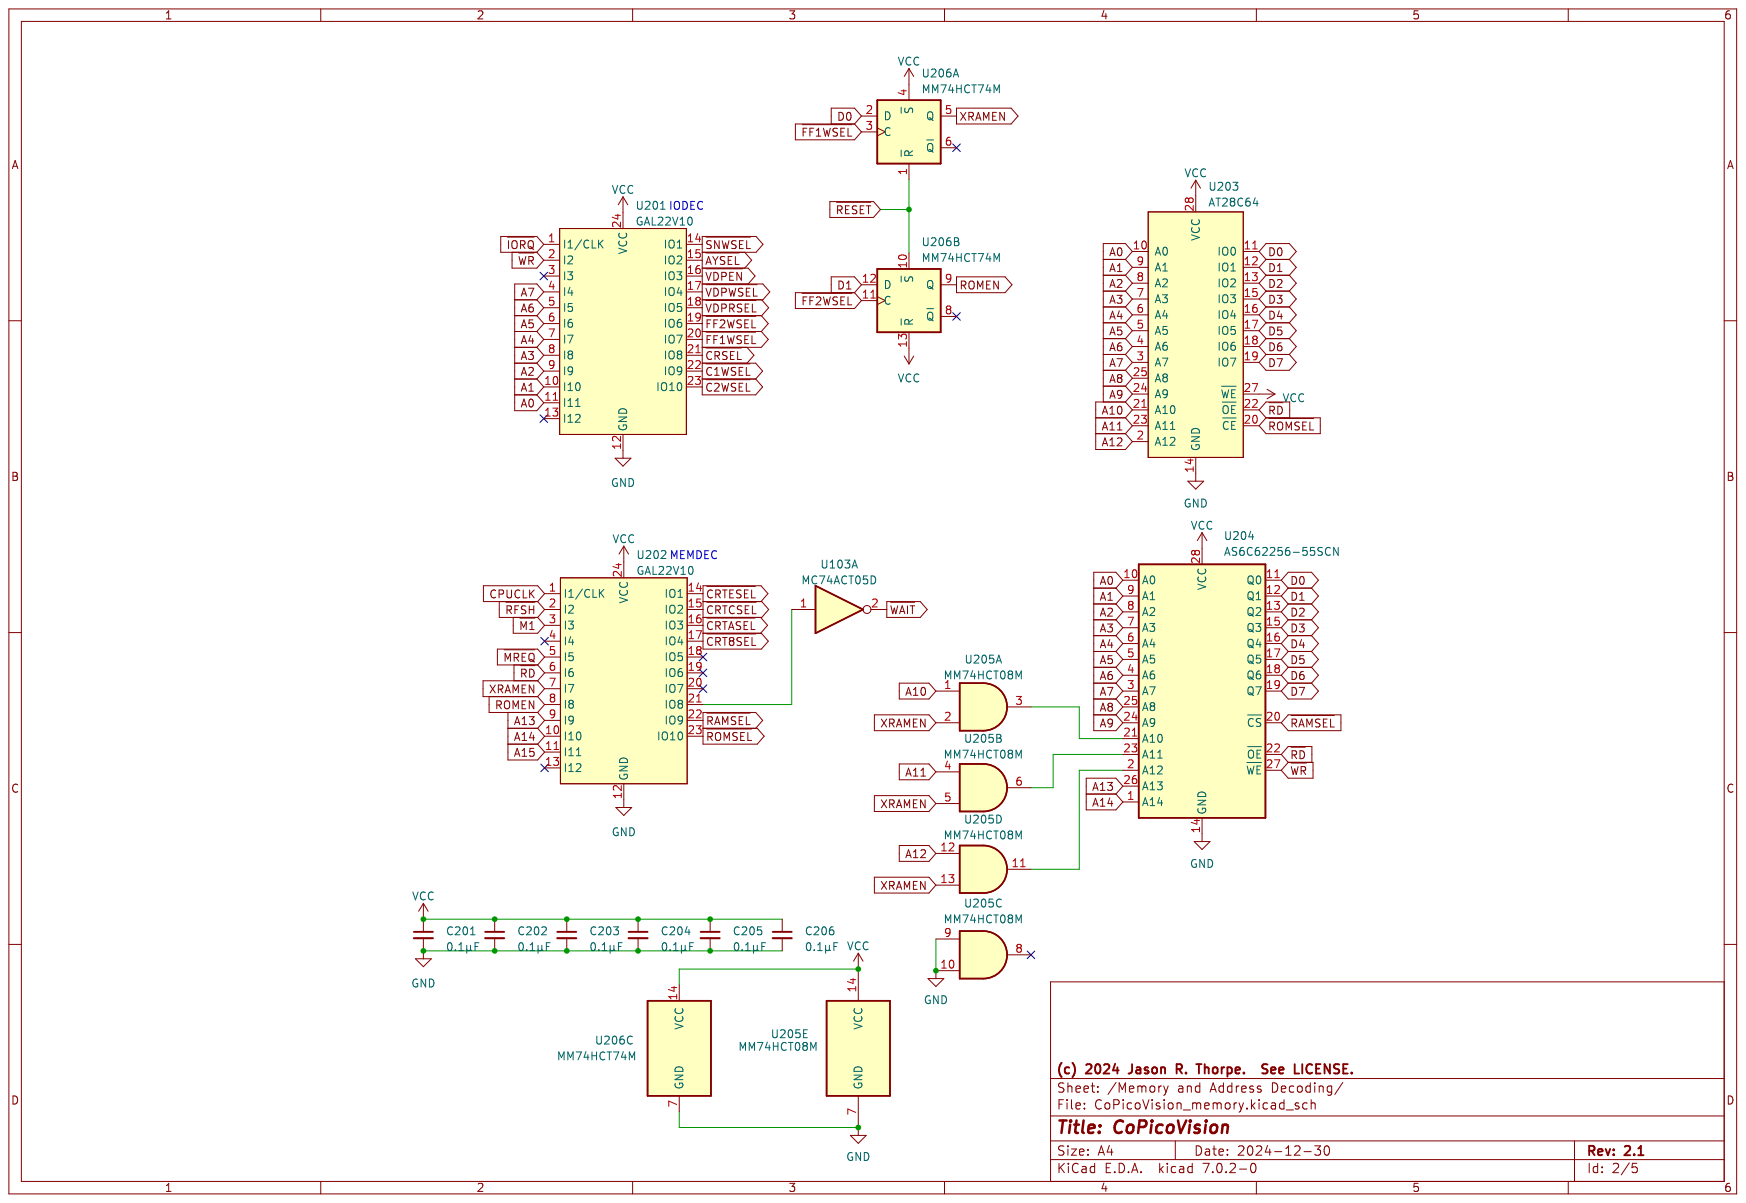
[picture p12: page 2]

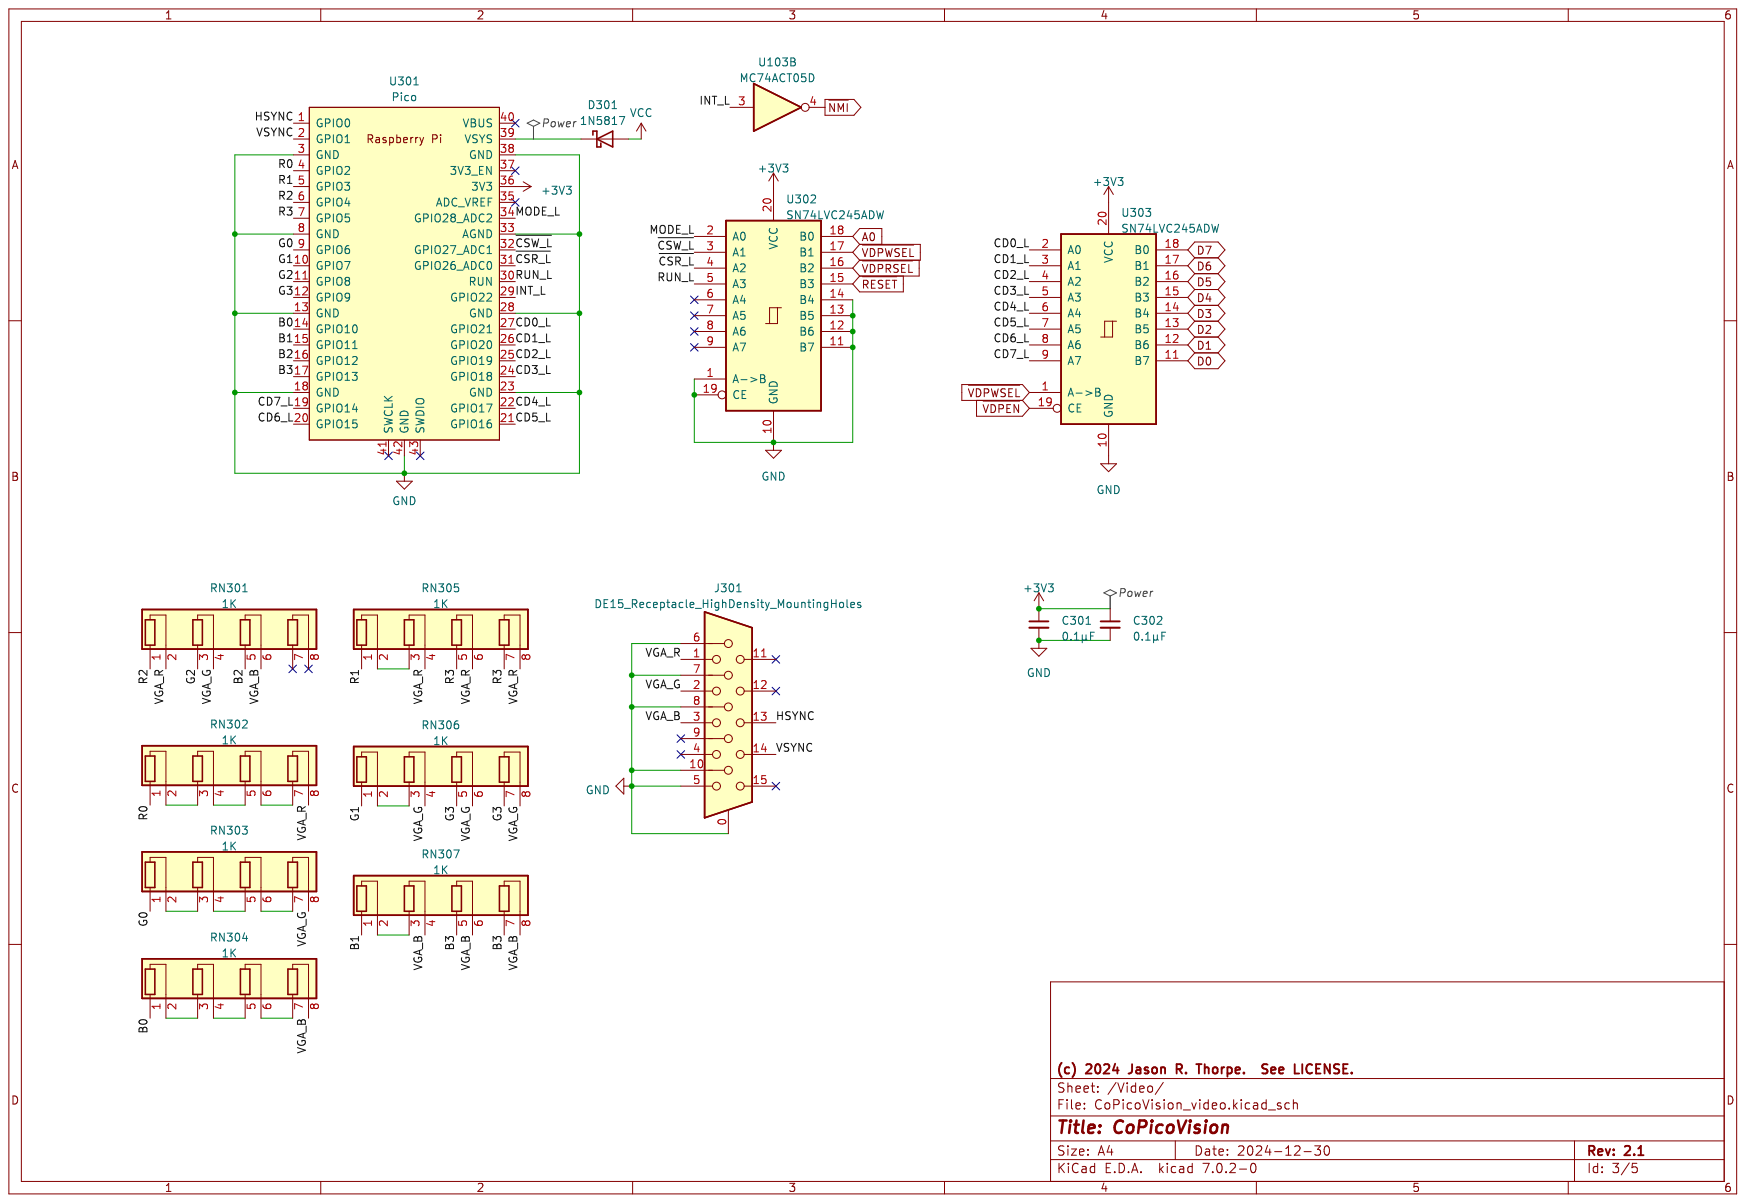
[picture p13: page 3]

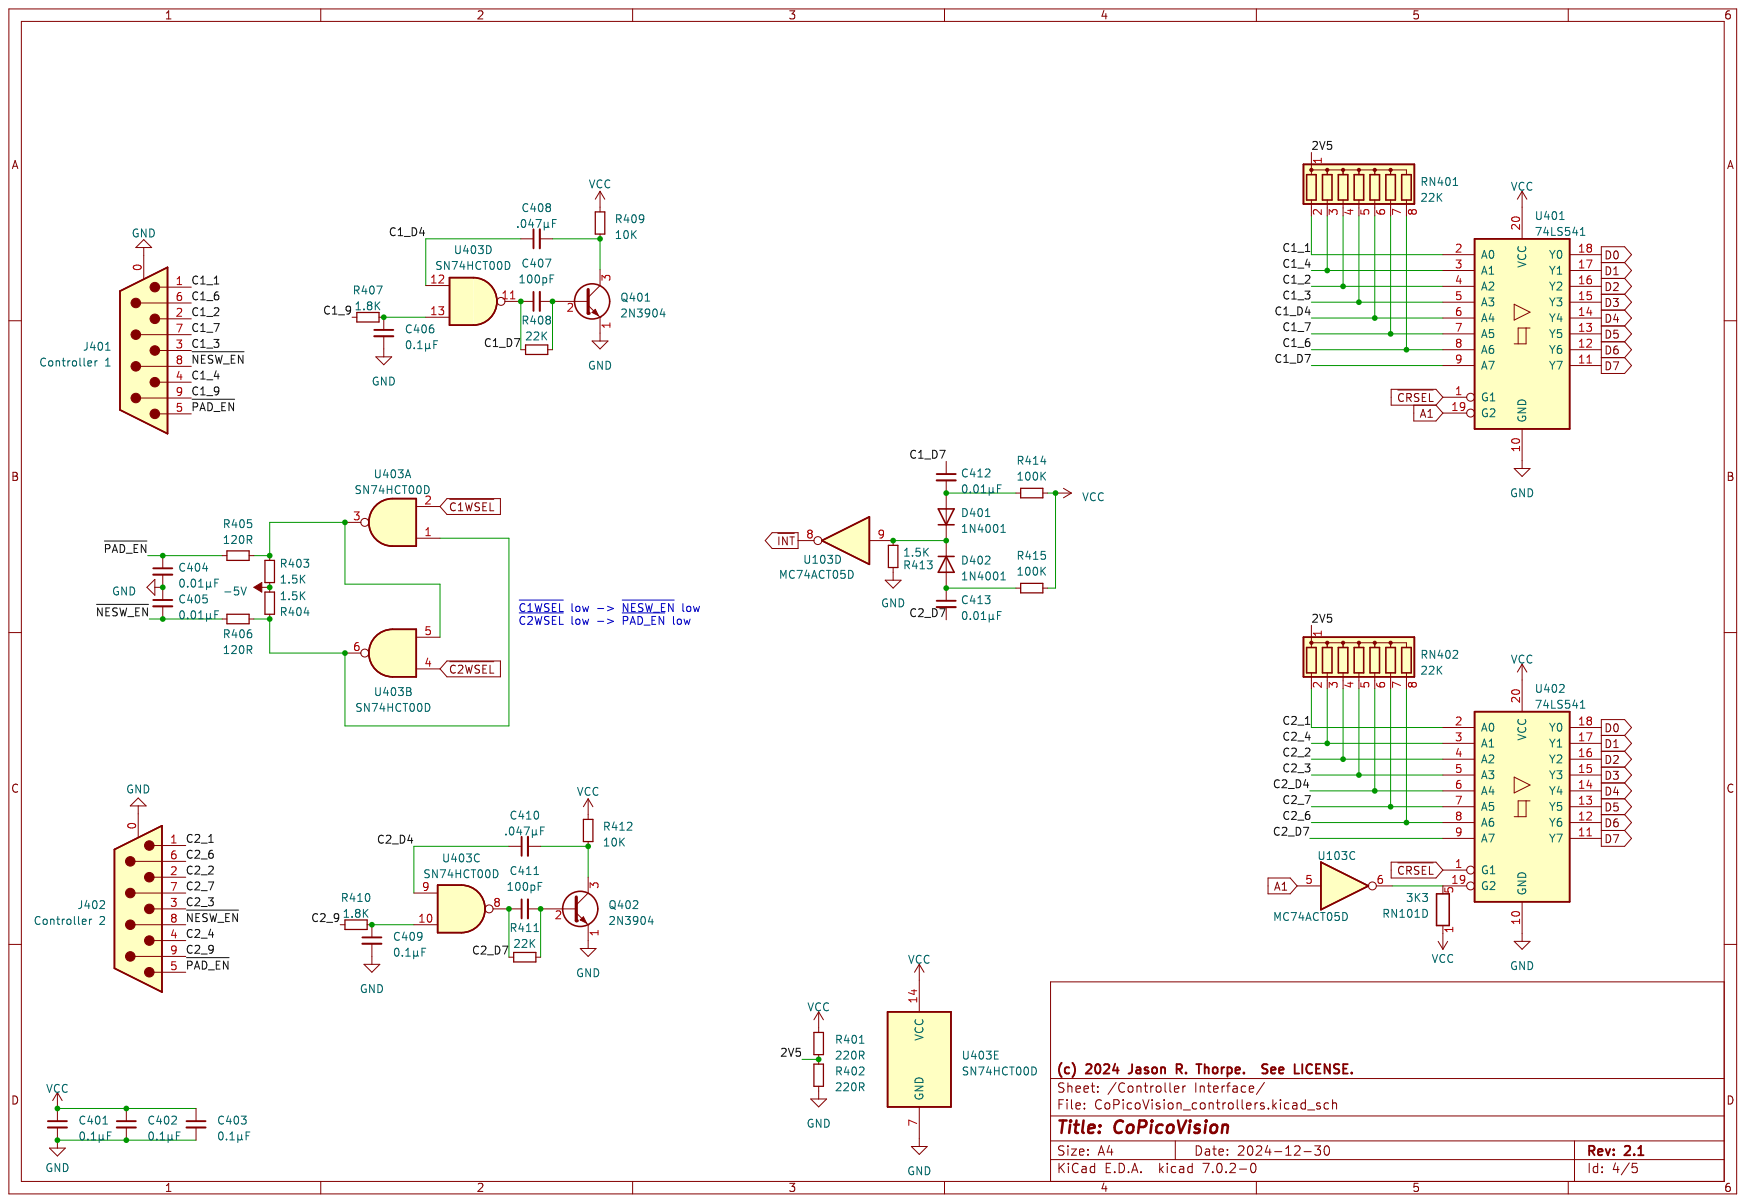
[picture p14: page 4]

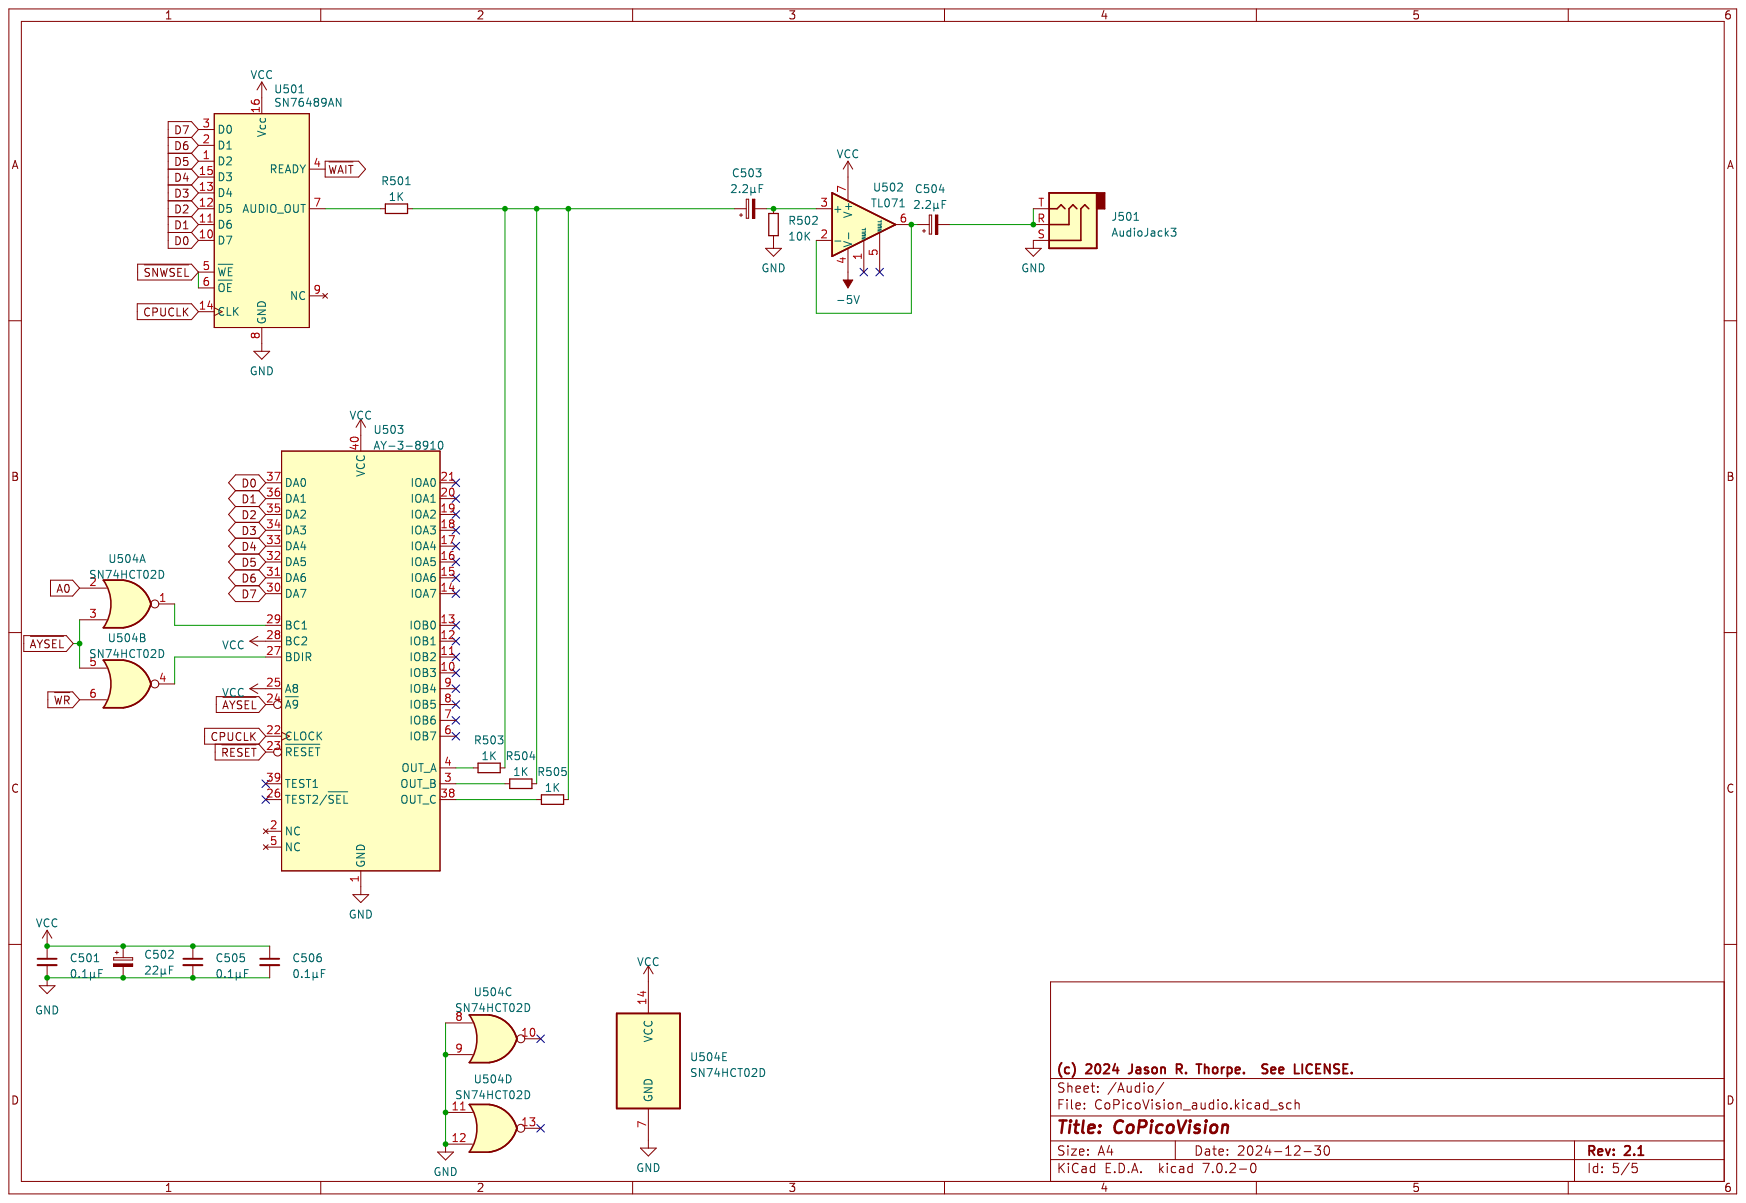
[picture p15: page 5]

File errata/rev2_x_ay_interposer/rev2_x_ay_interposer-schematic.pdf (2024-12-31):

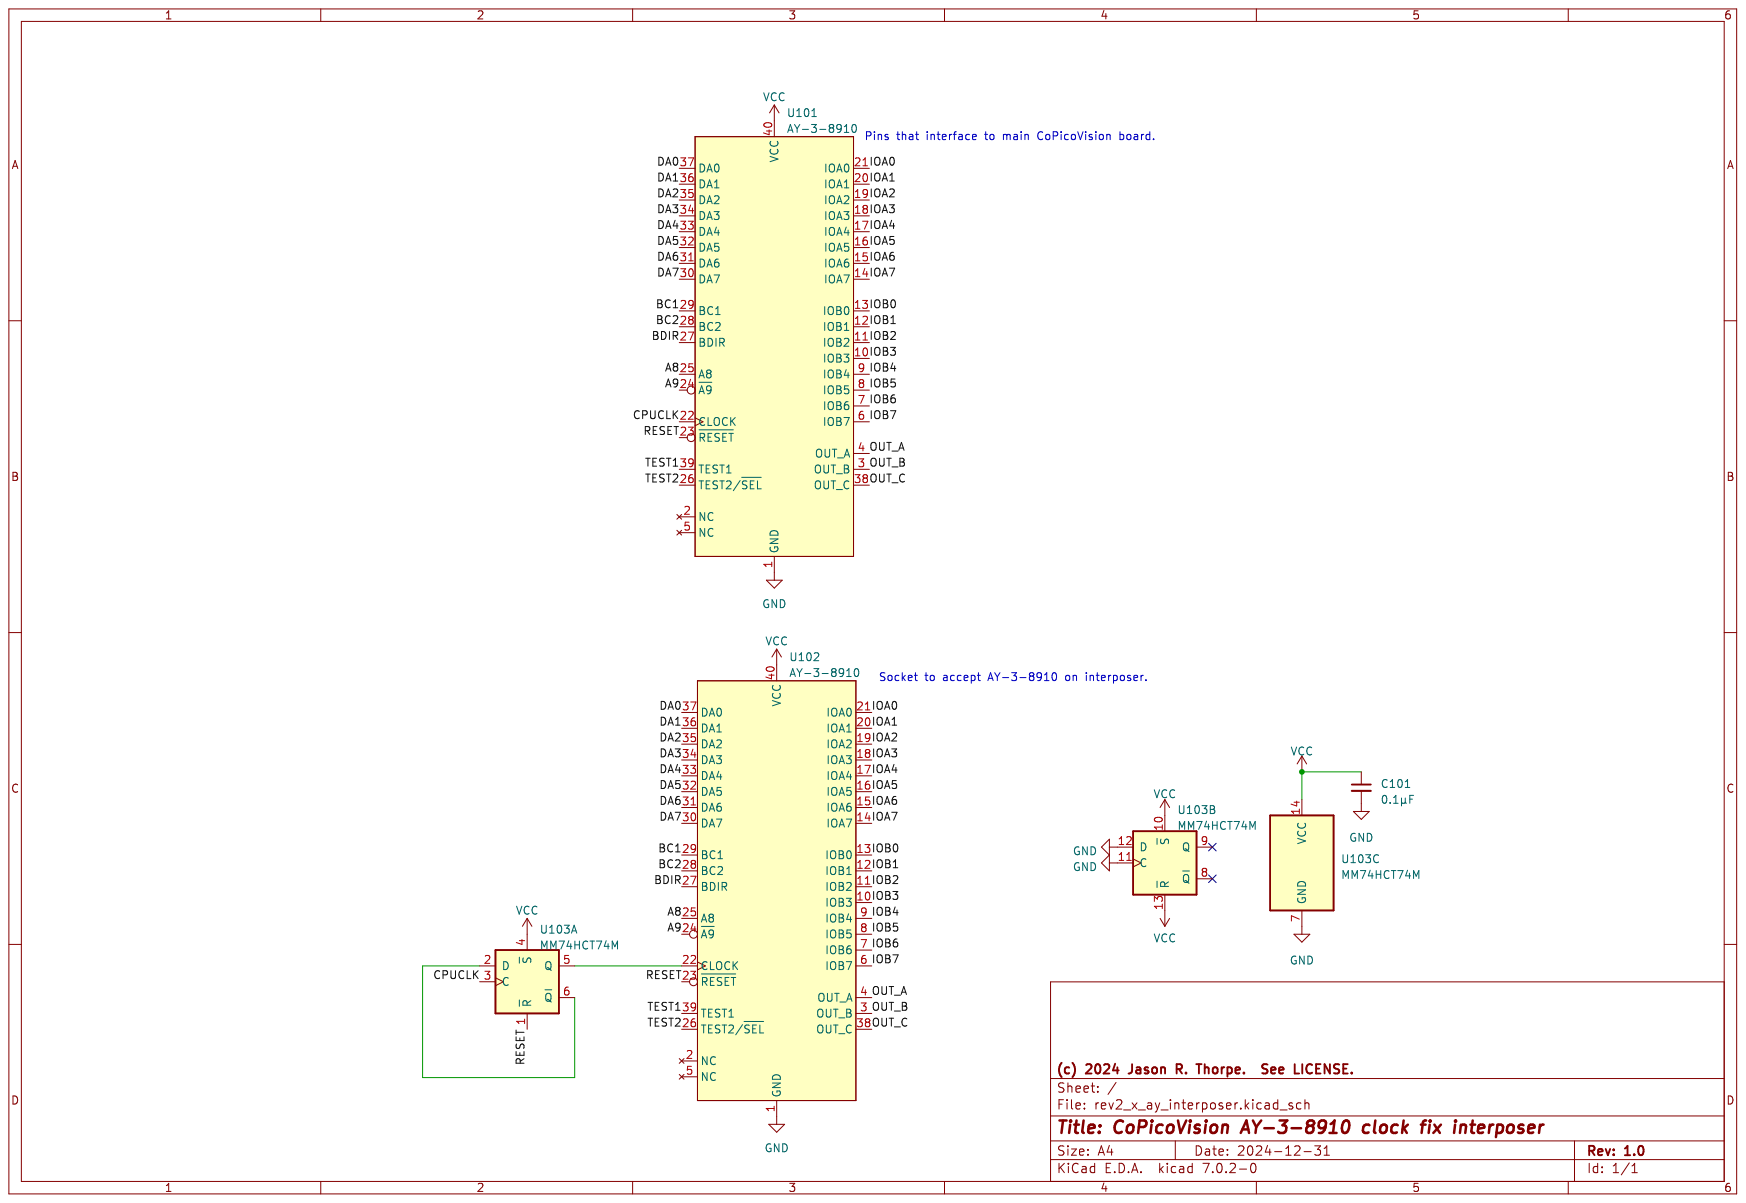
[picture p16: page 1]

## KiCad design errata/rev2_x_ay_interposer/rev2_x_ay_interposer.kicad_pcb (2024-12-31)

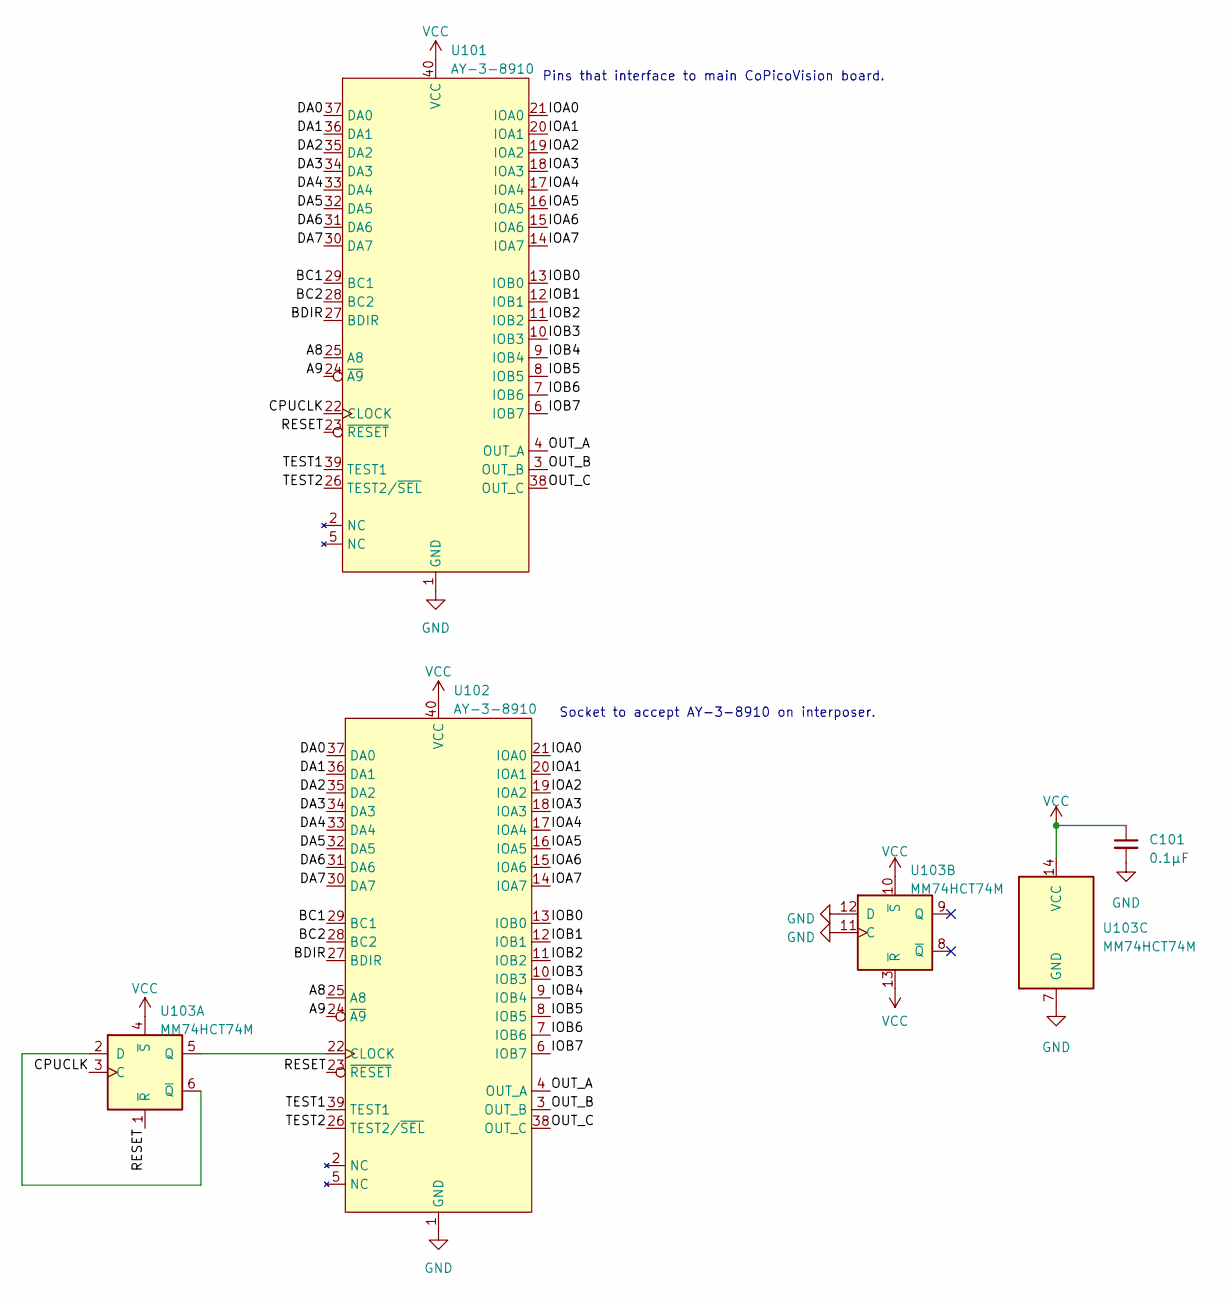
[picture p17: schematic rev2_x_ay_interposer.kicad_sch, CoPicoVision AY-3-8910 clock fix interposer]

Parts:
C101: 0.1µF; C_0805_2012Metric_Pad1.18x1.45mm_HandSolder
U101: AY-3-8910; DIP-40_W15.24mm
U102: AY-3-8910; DIP-40_W15.24mm_Socket
U103: MM74HCT74M; SOIC-14_3.9x8.7mm_P1.27mm; Mouser 512-MM74HCT74MX

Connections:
/A8: U101.25 (A8), U102.25 (A8)
/A9: U101.24 (~A9), U102.24 (~A9)
/BC1: U101.29 (BC1), U102.29 (BC1)
/BC2: U101.28 (BC2), U102.28 (BC2)
/BDIR: U101.27 (BDIR), U102.27 (BDIR)
/CPUCLK: U101.22 (CLOCK), U103.3 (C)
/DA0: U101.37 (DA0), U102.37 (DA0)
/DA1: U101.36 (DA1), U102.36 (DA1)
/DA2: U101.35 (DA2), U102.35 (DA2)
/DA3: U101.34 (DA3), U102.34 (DA3)
/DA4: U101.33 (DA4), U102.33 (DA4)
/DA5: U101.32 (DA5), U102.32 (DA5)
/DA6: U101.31 (DA6), U102.31 (DA6)
/DA7: U101.30 (DA7), U102.30 (DA7)
/IOA0: U101.21 (IOA0), U102.21 (IOA0)
/IOA1: U101.20 (IOA1), U102.20 (IOA1)
/IOA2: U101.19 (IOA2), U102.19 (IOA2)
/IOA3: U101.18 (IOA3), U102.18 (IOA3)
/IOA4: U101.17 (IOA4), U102.17 (IOA4)
/IOA5: U101.16 (IOA5), U102.16 (IOA5)
/IOA6: U101.15 (IOA6), U102.15 (IOA6)
/IOA7: U101.14 (IOA7), U102.14 (IOA7)
/IOB0: U101.13 (IOB0), U102.13 (IOB0)
/IOB1: U101.12 (IOB1), U102.12 (IOB1)
/IOB2: U101.11 (IOB2), U102.11 (IOB2)
/IOB3: U101.10 (IOB3), U102.10 (IOB3)
/IOB4: U101.9 (IOB4), U102.9 (IOB4)
/IOB5: U101.8 (IOB5), U102.8 (IOB5)
/IOB6: U101.7 (IOB6), U102.7 (IOB6)
/IOB7: U101.6 (IOB7), U102.6 (IOB7)
/OUT_A: U101.4 (OUT_A), U102.4 (OUT_A)
/OUT_B: U101.3 (OUT_B), U102.3 (OUT_B)
/OUT_C: U101.38 (OUT_C), U102.38 (OUT_C)
/RESET: U101.23 (~RESET), U102.23 (~RESET), U103.1 (~R)
/TEST1: U101.39 (TEST1), U102.39 (TEST1)
/TEST2: U101.26 (TEST2/~SEL), U102.26 (TEST2/~SEL)
GND: C101.2, U101.1 (GND), U102.1 (GND), U103.7 (GND), U103.11 (C), U103.12 (D)
unnamed: U102.22 (CLOCK), U103.5 (Q)
unnamed: U103.2 (D), U103.6 (~Q)
VCC: C101.1, U101.40 (VCC), U102.40 (VCC), U103.4 (~S), U103.10 (~S), U103.13 (~R), U103.14 (VCC)

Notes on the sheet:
Socket to accept AY-3-8910 on interposer.
Pins that interface to main CoPicoVision board.

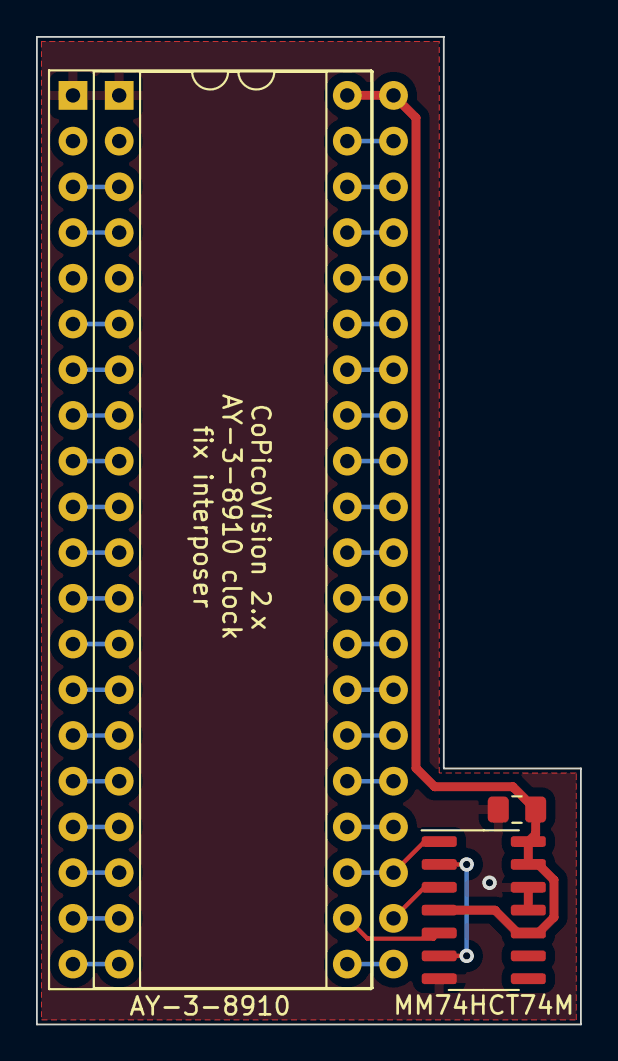
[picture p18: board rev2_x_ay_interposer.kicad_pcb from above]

Board: 2 copper layers, 30.2 x 54.9 mm, 4 parts (0 on the bottom side), 40 nets.

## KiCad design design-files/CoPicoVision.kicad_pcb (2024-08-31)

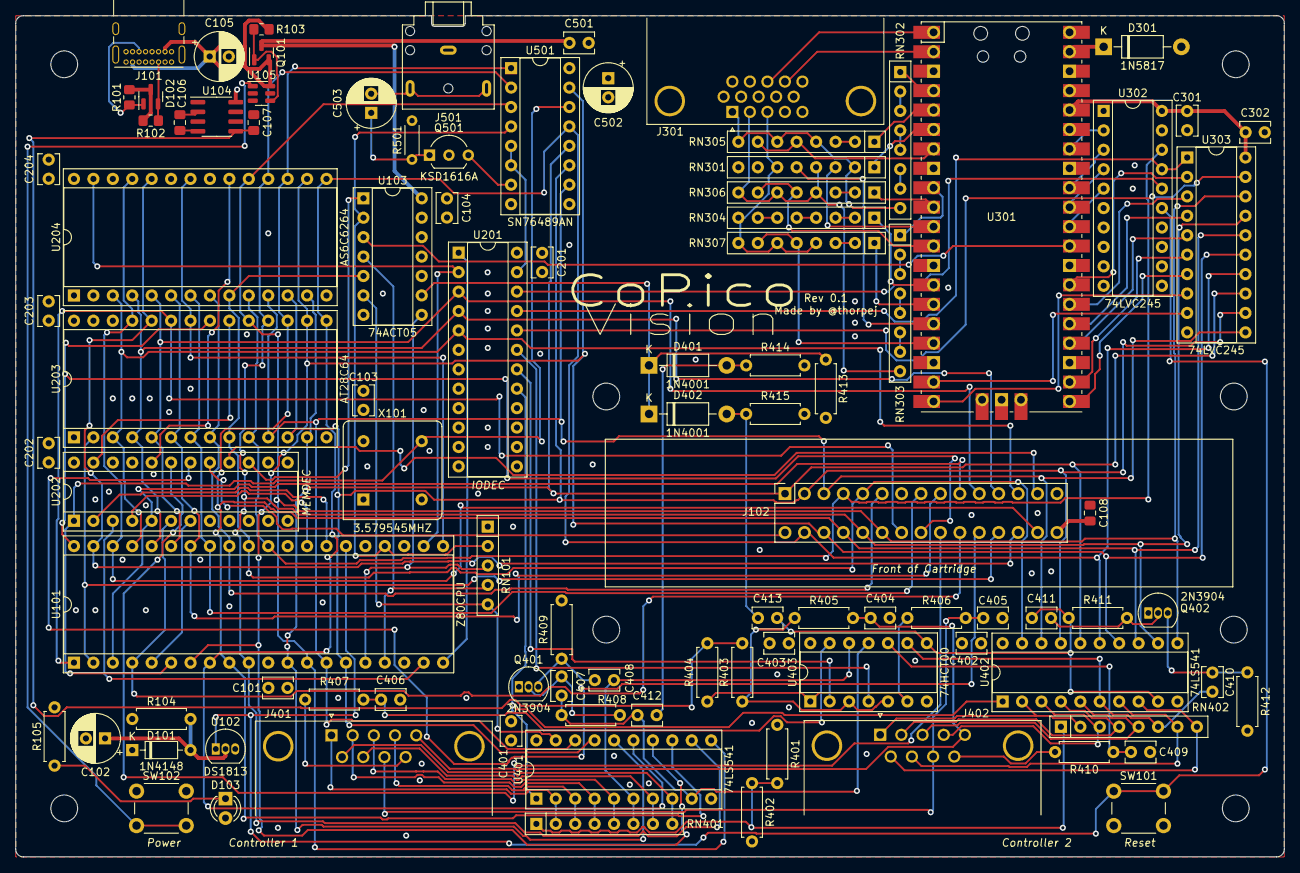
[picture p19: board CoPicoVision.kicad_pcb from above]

Board: 4 copper layers, 165.9 x 110.0 mm, 104 parts (0 on the bottom side), 141 nets.

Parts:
C101, C103, C104, C201, C202, C203, C204, C301, C302, C401, C402, C403, C406, C409, C501: 0.1µF; C_Disc_D3.8mm_W2.6mm_P2.50mm
C102, C105: 100µF; CP_Radial_D6.3mm_P2.50mm
C106, C107: 10µF; C_0805_2012Metric_Pad1.18x1.45mm_HandSolder
C108: 0.1µF; C_0805_2012Metric_Pad1.18x1.45mm_HandSolder
C404, C405, C412, C413: 0.01µF; C_Disc_D3.8mm_W2.6mm_P2.50mm
C407, C411: 100pF; C_Disc_D3.8mm_W2.6mm_P2.50mm
C408, C410: .047µF; C_Disc_D3.8mm_W2.6mm_P2.50mm
C502: 10µF; CP_Radial_D6.3mm_P2.50mm
C503: 470µF; CP_Radial_D6.3mm_P2.50mm
D101: 1N4148; D_DO-35_SOD27_P7.62mm_Horizontal
D102: ESDA25L; SOT-23
D103: Power LED; LED_D3.0mm
D301: 1N5817; D_DO-41_SOD81_P10.16mm_Horizontal
D401, D402: 1N4001; D_DO-41_SOD81_P10.16mm_Horizontal
H101, H102, H103, H104, H105, H106, H107, H108: MountingHole; MountingHole_3.5mm
J101: USB_C_Receptacle_PowerOnly_6P; USB_C_Receptacle_GCT_USB4085
J102: Conn_02x15_Odd_Even; Sullins_Cart_Slot
J301: DE15_Receptacle_HighDensity_MountingHoles; DSUB-15-HD_Female_Horizontal_P2.29x1.98mm_EdgePinOffset8.35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
J401: Controller 1; DSUB-9_Male_Horizontal_P2.77x2.84mm_EdgePinOffset7.70mm_Hou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
J402: Controller 2; DSUB-9_Male_Horizontal_P2.77x2.84mm_EdgePinOffset7.70mm_Hou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
J501: AudioJack3; Jack_3.5mm_CUI_SJ1-3523N_Horizontal
Q101: MMFTP3334K-AQ; SOT-23
Q401, Q402: 2N3904; TO-92_Inline
Q501: KSD1616A; TO-92L_Inline_Wide
R101, R102: 5K1; R_0805_2012Metric_Pad1.20x1.40mm_HandSolder
R103: 10K; R_0805_2012Metric_Pad1.20x1.40mm_HandSolder
R104: 3K3; R_Axial_DIN0207_L6.3mm_D2.5mm_P7.62mm_Horizontal
R105: 330R; R_Axial_DIN0207_L6.3mm_D2.5mm_P7.62mm_Horizontal
R401, R402: 210R; R_Axial_DIN0207_L6.3mm_D2.5mm_P7.62mm_Horizontal
R403, R404, R413: 1.5K; R_Axial_DIN0207_L6.3mm_D2.5mm_P7.62mm_Horizontal
R405, R406: 120R; R_Axial_DIN0207_L6.3mm_D2.5mm_P7.62mm_Horizontal
R407, R410: 1.8K; R_Axial_DIN0207_L6.3mm_D2.5mm_P7.62mm_Horizontal
R408, R411: 22K; R_Axial_DIN0207_L6.3mm_D2.5mm_P7.62mm_Horizontal
R409, R412: 10K; R_Axial_DIN0207_L6.3mm_D2.5mm_P7.62mm_Horizontal
R414, R415: 100K; R_Axial_DIN0207_L6.3mm_D2.5mm_P7.62mm_Horizontal
R501: 100R; R_Axial_DIN0204_L3.6mm_D1.6mm_P5.08mm_Horizontal
RN101: 3K3; R_Array_SIP5
RN301, RN302, RN303, RN304, RN305, RN306, RN307: 1K; R_Array_SIP8
RN401, RN402: 22K; R_Array_SIP8
SW101, SW102: SW_Push; SW_PUSH_6mm
U101: Z80CPU; DIP-40_W15.24mm_Socket
U102: DS1813; TO-92_Inline
U103: 74ACT05; DIP-14_W7.62mm_Socket
U104: ICL7660A; SOIC-8_3.9x4.9mm_P1.27mm
U105: MAX16054; SOT-23-6
U201, U202: GAL22V10; DIP-24_W7.62mm_Socket
U203: AT28C64; DIP-28_W15.24mm_Socket
U204: AS6C6264; DIP-28_W15.24mm_Socket
U301: Pico; RPi_Pico_SMD_TH
U302, U303: 74LVC245; DIP-20_W7.62mm_Socket
U401, U402: 74LS541; DIP-20_W7.62mm_Socket
U403: 74HCT00; DIP-14_W7.62mm_Socket
U501: SN76489AN; DIP-16_W7.62mm_Socket
X101: 3.579545MHZ; Oscillator_DIP-8

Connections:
+3V3: C301.1, C302.1, U301.36 (3V3), U302.20 (VCC), U303.20 (VCC)
-5V: C107.1, R403.2, R404.2, U104.5 (VOUT)
/Controller Interface/2V5: R401.2, R402.1, RN401.1 (common), RN402.1 (common)
/Controller Interface/C1_1: J401.1, RN401.2 (R1), U401.2 (A0)
/Controller Interface/C1_2: J401.2, RN401.4 (R3), U401.4 (A2)
/Controller Interface/C1_3: J401.3, RN401.5 (R4), U401.5 (A3)
/Controller Interface/C1_4: J401.4, RN401.3 (R2), U401.3 (A1)
/Controller Interface/C1_6: J401.6, RN401.8 (R7), U401.8 (A6)
/Controller Interface/C1_7: J401.7, RN401.7 (R6), U401.7 (A5)
/Controller Interface/C1_9: J401.9, R407.1
/Controller Interface/C1_D4: C408.1, RN401.6 (R5), U401.6 (A4), U403.12
/Controller Interface/C1_D7: C407.1, C412.1, R408.1, U401.9 (A7), U403.11
/Controller Interface/C2_1: J402.1, RN402.2 (R1), U402.2 (A0)
/Controller Interface/C2_2: J402.2, RN402.4 (R3), U402.4 (A2)
/Controller Interface/C2_3: J402.3, RN402.5 (R4), U402.5 (A3)
/Controller Interface/C2_4: J402.4, RN402.3 (R2), U402.3 (A1)
/Controller Interface/C2_6: J402.6, RN402.8 (R7), U402.8 (A6)
/Controller Interface/C2_7: J402.7, RN402.7 (R6), U402.7 (A5)
/Controller Interface/C2_9: J402.9, R410.1
/Controller Interface/C2_D4: C410.1, RN402.6 (R5), U402.6 (A4), U403.9
/Controller Interface/C2_D7: C411.1, C413.2, R411.1, U402.9 (A7), U403.8
/Controller Interface/~NESW_EN: C405.2, J401.8, J402.8, R406.1
/Controller Interface/~PAD_EN: C404.1, J401.5, J402.5, R405.1
/VBUS: C105.1, J101.A9 (VBUS), J101.B9 (VBUS), Q101.2 (S), R103.1, U105.6 (Vcc)
/Video/B0: RN304.1 (R1.1), U301.14 (GPIO10)
/Video/B1: RN307.1 (R1.1), U301.15 (GPIO11)
/Video/B2: RN301.5 (R3.1), U301.16 (GPIO12)
/Video/B3: RN307.5 (R3.1), RN307.7 (R4.1), U301.17 (GPIO13)
/Video/CD0_L: U301.27 (GPIO21), U303.2 (A0)
/Video/CD1_L: U301.26 (GPIO20), U303.3 (A1)
/Video/CD2_L: U301.25 (GPIO19), U303.4 (A2)
/Video/CD3_L: U301.24 (GPIO18), U303.5 (A3)
/Video/CD4_L: U301.22 (GPIO17), U303.6 (A4)
/Video/CD5_L: U301.21 (GPIO16), U303.7 (A5)
/Video/CD6_L: U301.20 (GPIO15), U303.8 (A6)
/Video/CD7_L: U301.19 (GPIO14), U303.9 (A7)
/Video/G0: RN303.1 (R1.1), U301.9 (GPIO6)
/Video/G1: RN306.1 (R1.1), U301.10 (GPIO7)
/Video/G2: RN301.3 (R2.1), U301.11 (GPIO8)
/Video/G3: RN306.5 (R3.1), RN306.7 (R4.1), U301.12 (GPIO9)
/Video/HSYNC: J301.13, U301.1 (GPIO0)
/Video/INT_L: U103.3, U301.29 (GPIO22)
/Video/MODE_L: U301.34 (GPIO28_ADC2), U302.2 (A0)
/Video/R0: RN302.1 (R1.1), U301.4 (GPIO2)
/Video/R1: RN305.1 (R1.1), U301.5 (GPIO3)
/Video/R2: RN301.1 (R1.1), U301.6 (GPIO4)
/Video/R3: RN305.5 (R3.1), RN305.7 (R4.1), U301.7 (GPIO5)
/Video/RUN_L: U301.30 (RUN), U302.5 (A3)
/Video/VGA_B: J301.3, RN301.6 (R3.2), RN304.8 (R4.2), RN307.4 (R2.2), RN307.6 (R3.2), RN307.8 (R4.2)
/Video/VGA_G: J301.2, RN301.4 (R2.2), RN303.8 (R4.2), RN306.4 (R2.2), RN306.6 (R3.2), RN306.8 (R4.2)
/Video/VGA_R: J301.1, RN301.2 (R1.2), RN302.8 (R4.2), RN305.4 (R2.2), RN305.6 (R3.2), RN305.8 (R4.2)
/Video/VSYNC: J301.14, U301.2 (GPIO1)
/Video/~CSR_L: U301.31 (GPIO26_ADC0), U302.4 (A2)
/Video/~CSW_L: U301.32 (GPIO27_ADC1), U302.3 (A1)
A0: J102.7, U101.30 (A0), U203.10 (A0), U204.10 (A0), U302.18 (B0)
A1: J102.9, U101.31 (A1), U103.5, U203.9 (A1), U204.9 (A1), U402.19 (G2)
A2: J102.11, U101.32 (A2), U203.8 (A2), U204.8 (A2)
A3: J102.15, U101.33 (A3), U203.7 (A3), U204.7 (A3)
A4: J102.17, U101.34 (A4), U203.6 (A4), U204.6 (A4)
A5: J102.21, U101.35 (A5), U201.3 (I3), U203.5 (A5), U204.5 (A5)
A6: J102.23, U101.36 (A6), U201.4 (I4), U203.4 (A6), U204.4 (A6)
A7: J102.25, U101.37 (A7), U201.5 (I5), U203.3 (A7), U204.3 (A7)
A8: J102.28, U101.38 (A8), U203.25 (A8), U204.25 (A8)
A9: J102.26, U101.39 (A9), U203.24 (A9), U204.24 (A9)
A10: J102.16, U101.40 (A10), U203.21 (A10)
A11: J102.14, U101.1 (A11), U203.23 (A11)
A12: J102.24, U101.2 (A12), U203.2 (A12)
A13: J102.19, U101.3 (A13), U202.5 (I5)
A14: J102.20, U101.4 (A14), U202.6 (I6)
A15: U101.5 (A15), U202.7 (I7)
CPUCLK: U101.6 (~CLK), U202.1 (I1/CLK), U501.14 (CLK), X101.5 (OUT)
D0: J102.5, U101.14 (D0), U203.11 (IO0), U204.11 (DQ0), U303.11 (B7), U401.18 (Y0), U402.18 (Y0), U501.10 (D7)
D1: J102.3, U101.15 (D1), U203.12 (IO1), U204.12 (DQ1), U303.12 (B6), U401.17 (Y1), U402.17 (Y1), U501.11 (D6)
D2: J102.1, U101.12 (D2), U203.13 (IO2), U204.13 (DQ2), U303.13 (B5), U401.16 (Y2), U402.16 (Y2), U501.12 (D5)
D3: J102.4, U101.8 (D3), U203.15 (IO3), U204.15 (DQ3), U303.14 (B4), U401.15 (Y3), U402.15 (Y3), U501.13 (D4)
D4: J102.6, U101.7 (D4), U203.16 (IO4), U204.16 (DQ4), U303.15 (B3), U401.14 (Y4), U402.14 (Y4), U501.15 (D3)
D5: J102.8, U101.9 (D5), U203.17 (IO5), U204.17 (DQ5), U303.16 (B2), U401.13 (Y5), U402.13 (Y5), U501.1 (D2)
D6: J102.10, U101.10 (D6), U203.18 (IO6), U204.18 (DQ6), U303.17 (B1), U401.12 (Y6), U402.12 (Y6), U501.2 (D1)
D7: J102.12, U101.13 (D7), U203.19 (IO7), U204.19 (DQ7), U303.18 (B0), U401.11 (Y7), U402.11 (Y7), U501.3 (D0)
GND: C101.2, C102.2, C103.2, C104.2, C105.2, C107.2, C108.2, C201.2, C202.2, C203.2, C204.2, C301.2, C302.2, C401.2, C402.2, C403.2, C404.2, C405.1, C406.2, C409.2, C501.2, C502.2, D102.3 (A), J101.A12 (GND), J101.B12 (GND), J101.S1 (SHIELD), J102.13, J102.29, J301.0, J301.5, J301.6, J301.7, J301.8, J301.10, J401.0 (PAD), J402.0 (PAD), J501.S, Q401.1 (E), Q402.1 (E), R101.2, R102.2, R105.1, R402.2, R413.1, R501.2, SW101.2, SW102.1, U101.29 (GND), U102.3 (GND), U103.7 (GND), U103.11, U103.13, U104.3 (GND), U105.2 (GND), U105.3 (CLEAR), U201.12 (GND), U202.12 (GND), U203.14 (GND), U204.2 (A12), U204.14 (VSS), U204.21 (A10), U204.23 (A11), U301.3 (GND), U301.8 (GND), U301.13 (GND), U301.18 (GND), U301.23 (GND), U301.28 (GND), U301.33 (AGND), U301.38 (GND), U301.42 (GND), U302.1 (A->B), U302.10 (GND), U302.11 (B7), U302.12 (B6), U302.13 (B5), U302.14 (B4), U302.19 (CE), U303.10 (GND), U401.10 (GND), U402.10 (GND), U403.7 (GND), U501.8 (GND), X101.4 (GND)
unnamed: C406.1, R407.2, U403.13
unnamed: C409.1, R410.2, U403.10
unnamed: C503.2, J501.R, J501.T
unnamed: C102.1, D101.2 (A), R104.1, U102.2 (Vcc)
unnamed: D103.1 (K), R105.2
unnamed: D301.1 (K), U301.39 (VSYS)
unnamed: C412.2, D401.2 (A), R414.1
unnamed: D401.1 (K), D402.1 (K), R413.2, U103.9
unnamed: C413.1, D402.2 (A), R415.1
unnamed: D102.2 (K), J101.A5 (CC1), R102.1
unnamed: D102.1 (K), J101.B5 (CC2), R101.1
unnamed: Q101.1 (G), R103.2, U105.4 (~OUT)
unnamed: C407.2, Q401.2 (B), R408.2
unnamed: C408.2, Q401.3 (C), R409.1
unnamed: C411.2, Q402.2 (B), R411.2
unnamed: C410.2, Q402.3 (C), R412.1
unnamed: Q501.3 (B), U501.7 (AUDIO_OUT)
unnamed: C503.1, Q501.1 (E), R501.1
unnamed: R403.1, R405.2, U403.3, U403.5
unnamed: R404.1, R406.2, U403.1, U403.6
unnamed: RN101.5 (R4.2), U103.6, U401.19 (G2)
unnamed: RN302.2 (R1.2), RN302.3 (R2.1)
unnamed: RN302.4 (R2.2), RN302.5 (R3.1)
unnamed: RN302.6 (R3.2), RN302.7 (R4.1)
unnamed: RN303.2 (R1.2), RN303.3 (R2.1)
unnamed: RN303.4 (R2.2), RN303.5 (R3.1)
unnamed: RN303.6 (R3.2), RN303.7 (R4.1)
unnamed: RN304.2 (R1.2), RN304.3 (R2.1)
unnamed: RN304.4 (R2.2), RN304.5 (R3.1)
unnamed: RN304.6 (R3.2), RN304.7 (R4.1)
unnamed: RN305.2 (R1.2), RN305.3 (R2.1)
unnamed: RN306.2 (R1.2), RN306.3 (R2.1)
unnamed: RN307.2 (R1.2), RN307.3 (R2.1)
unnamed: C106.1, U104.2 (CAP+)
unnamed: C106.2, U104.4 (CAP-)
unnamed: SW102.2, U105.1 (IN)
unnamed: U103.1, U202.15 (IO2)
VCC: C101.1, C103.1, C104.1, C108.1, C201.1, C202.1, C203.1, C204.1, C401.1, C402.1, C403.1, C501.1, C502.1, D101.1 (K), D103.2 (A), D301.2 (A), J102.30, Q101.3 (D), Q501.2 (C), R104.2, R401.1, R409.2, R412.2, R414.2, R415.2, RN101.1 (R1), U101.11 (VCC), U101.25 (~BUSRQ), U103.14 (VCC), U104.8 (V+), U201.24 (VCC), U202.24 (VCC), U203.27 (~WE), U203.28 (VCC), U204.26 (CE2), U204.28 (VCC), U401.20 (VCC), U402.20 (VCC), U403.14 (VCC), U501.16 (Vcc), X101.8 (Vcc)
~C1WSEL: U201.18 (IO5), U403.2
~C2WSEL: U201.19 (IO6), U403.4
~CRSEL: U201.17 (IO4), U401.1 (G1), U402.1 (G1)
~CRT8SEL: J102.18, U202.19 (IO6)
~CRTASEL: J102.22, U202.18 (IO5)
~CRTCSEL: J102.2, U202.17 (IO4)
~CRTESEL: J102.27, U202.16 (IO3)
~INT: RN101.3 (R2.2), U101.16 (~INT), U103.8
~IORQ: U101.20 (~IORQ), U201.1 (I1/CLK)
~M1: U101.27 (~M1), U202.2 (I2)
~MREQ: U101.19 (~MREQ), U202.3 (I3)
~NMI: RN101.4 (R3.2), U101.17 (~NMI), U103.4
~RAMSEL: U202.20 (IO7), U204.20 (CE#)
~RD: U101.21 (~RD), U203.22 (~OE), U204.22 (OE#)
~RESET: SW101.1, U101.26 (~RESET), U102.1 (~RST), U302.15 (B3)
~RFSH: U101.28 (~RFSH), U202.4 (I4)
~ROMSEL: U202.23 (IO10), U203.20 (~CE)
~SNWSEL: U201.23 (IO10), U501.5 (~WE), U501.6 (~OE)
~VDPEN: U201.20 (IO7), U303.19 (CE)
~VDPRSEL: U201.22 (IO9), U302.16 (B2)
~VDPWSEL: U201.21 (IO8), U302.17 (B1), U303.1 (A->B)
~WAIT: RN101.2 (R1.2), U101.24 (~WAIT), U103.2, U501.4 (READY)
~WR: U101.22 (~WR), U201.2 (I2), U204.27 (WE#)

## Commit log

2024-08-27 Add initial KiCad design files for CoPicoVision. First item: memory and address decoding.
    [CoPicoVision.kicad_pcb, CoPicoVision.kicad_sch, CoPicoVision_memory.kicad_sch]
2024-08-27 Reset and clock.
    [CoPicoVision.kicad_sch, CoPicoVision_memory.kicad_sch]
2024-08-27 Use a 74ACT05 rather than a 74LS05.
    [CoPicoVision.kicad_sch, CoPicoVision_memory.kicad_sch]
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2024-08-28 Get footprints on everything.
    [CoPicoVision.kicad_sch, CoPicoVision_memory.kicad_sch]
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2024-08-28 First pass at rough PCB layout.
    [CoPicoVision.kicad_pcb, CoPicoVision.kicad_sch]
2024-08-28 Add controller ports just to get them onto the board.
    [CoPicoVision.kicad_pcb, CoPicoVision.kicad_sch]
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2024-08-29 Lay out some additional bits.
    [CoPicoVision.kicad_pcb, CoPicoVision.kicad_sch]
2024-08-29 Add power supply. PCB checkpoint.
    [CoPicoVision.kicad_pcb, CoPicoVision.kicad_sch]
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2024-08-29 Getting closer with PCB layout.
    [CoPicoVision.kicad_pcb, CoPicoVision.kicad_sch, CoPicoVision_video.kicad_sch]
2024-08-29 Add mounting holes around the cartridge area to reinforce it when carts are being inserted.
    [CoPicoVision.kicad_pcb, CoPicoVision.kicad_sch]
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2024-08-30 PCB checkpoint -- some trace routing done.
    [CoPicoVision.kicad_pcb, CoPicoVision_video.kicad_sch]
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2024-08-30 Clean up net classes for power.
    [CoPicoVision.kicad_pcb, CoPicoVision.kicad_sch, CoPicoVision_video.kicad_sch]
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2024-08-30 Fix a reference placement.
    [CoPicoVision.kicad_pcb]
2024-08-30 Shorten a CPUCLK trace.
    [CoPicoVision.kicad_pcb]
2024-08-30 Checkpoint on controller circuit.
    [CoPicoVision.kicad_pcb, CoPicoVision.kicad_sch, CoPicoVision_controllers.kicad_sch]
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2024-08-31 Final controller checkpoint. Managed to sqeeeze it all onto the board.
    [CoPicoVision.kicad_pcb, CoPicoVision.kicad_sch, CoPicoVision_controllers.kicad_sch]
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2024-08-31 Most of the controller interface routed.
    [CoPicoVision.kicad_pcb, CoPicoVision_controllers.kicad_sch]
2024-08-31 Shuffle IODEC outputs to make layout easier.
    [CoPicoVision.kicad_pcb, CoPicoVision_memory.kicad_sch]
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2024-08-31 Use a discrete resistor for the PoR delay, rather than one from the 3K3 resistor pack.
    [CoPicoVision.kicad_pcb, CoPicoVision.kicad_sch]
2024-08-31 Use a 4-resistor pack, not 8.
    [CoPicoVision.kicad_pcb, CoPicoVision.kicad_sch, CoPicoVision_controllers.kicad_sch]
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2024-08-31 IODEC fully wired up.
    [CoPicoVision.kicad_pcb]
2024-08-31 Cart address bus wired up.
    [CoPicoVision.kicad_pcb]
2024-08-31 Cart slot all wired up. Yeesh.
    [CoPicoVision.kicad_pcb]
2024-08-31 Tweak verification rules -- passes now.
    [CoPicoVision.kicad_sch, CoPicoVision_video.kicad_sch]
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2024-08-31 Add a power LED.
    [CoPicoVision.kicad_sch, CoPicoVision_controllers.kicad_sch]
2024-08-31 Move the D103 reference.
    [CoPicoVision.kicad_pcb]
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2024-09-02 Double-check physical dimensions for mounting holes and adjust a few to get them all lined up correctly. Tweak cartridge opening outline to be perfectly[*] centered vis a vis the edge connector.
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2024-10-12 Add a procedure to fix the swapped controller problem on rev 0.1 boards.
2024-10-12 Link in the procedure to fix the swapped controller problem on rev 0.1 boards.
2024-10-12 Fix the swapped controller problem that rev 0.1 boards have: the G2 input of the 74LS541 is active-low, so A1 low means Controller 1 is selected.
    [CoPicoVision_controllers.kicad_sch]
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2024-10-12 PCB fix for rev 0.1 swapped controller bug.
2024-10-12 Status update: schematic and PCB fixed for swapped controller bug.
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2024-10-16 Add a 1.5K current limiting resistor between the SN76489AN audio output and the KSD1616A emitter-follower.
    [CoPicoVision_audio.kicad_sch, CoPicoVision_controllers.kicad_sch]
2024-10-16 Add a 0.01uF cap to ground to the emitter-follower input to form a ~10KHz low-pass filter to try and tamp down the hissy noise.
    [CoPicoVision_audio.kicad_sch]
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2024-10-17 The cartridge connector is about 1.5mm too close to the front of the board, not 2mm.
2024-12-15 Project update, and use a TL071 opamp for the audio output buffer.
    [CoPicoVision_audio.kicad_sch]
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2024-12-16 A couple more SMT resistors on the main sheet.
    [CoPicoVision.kicad_sch]
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2024-12-17 Make the SRAM SMT. Man, this frees up a lot of real-estate.
    [CoPicoVision.kicad_pcb]
2024-12-17 Add the SGM memory logic chips, clean out board routing on the left half of the board.
    [CoPicoVision.kicad_pcb, CoPicoVision_memory.kicad_sch]
2024-12-17 Move the IODEC and MEMDEC chips around. They will be re-pinned to make this layout work better.
    [CoPicoVision.kicad_pcb]
2024-12-17 Re-pin the inputs of the IODEC GAL, and make it take A0-A7 in prep for SGM additions.
    [CoPicoVision.kicad_pcb, CoPicoVision_memory.kicad_sch]
2024-12-17 Rearrange the MEMDEC GAL to work better with the new board layout.
    [CoPicoVision.kicad_pcb, CoPicoVision_memory.kicad_sch]
2024-12-17 Fix a keep-out.
    [CoPicoVision.kicad_pcb]
2024-12-17 Add the XRAMEN and ROMEN signals to the MEMDEC GAL.
    [CoPicoVision.kicad_pcb, CoPicoVision_memory.kicad_sch]
2024-12-17 Add all of the SGM IODEC signals and re-pin the outputs to work better with the new board layout.
    [CoPicoVision.kicad_pcb, CoPicoVision_memory.kicad_sch]
2024-12-18 Route most of the address / data lines.
    [CoPicoVision.kicad_pcb, CoPicoVision_memory.kicad_sch]
2024-12-18 Put the AY-3-8910 on the schematic. Need to make some more room on the board.
    [CoPicoVision.kicad_pcb, CoPicoVision_audio.kicad_sch]
2024-12-18 Move the video module to the right, making room for the AY-3-8910.
    [CoPicoVision.kicad_pcb]
2024-12-18 Put the AY-3-8910 on the board, clarify part numbers for the 74xx chips to ensure the correct SOIC footprints.
    [CoPicoVision.kicad_pcb, CoPicoVision.kicad_sch, CoPicoVision_audio.kicad_sch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]
2024-12-18 I think that's the whole right side of the board now routed.
    [CoPicoVision.kicad_pcb, CoPicoVision_audio.kicad_sch]
2024-12-18 I think that's all the address lines now.
    [CoPicoVision.kicad_pcb]
2024-12-18 Fix a dumb mistake in the power supply (put the reservoir cap on VCC, not VBUS), and fix a bunch of unconnected items.
    [CoPicoVision.kicad_pcb, CoPicoVision.kicad_sch]
2024-12-19 Give a slightly more generous footprint to the RAM chip.
    [CoPicoVision_memory.kicad_sch]
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2024-12-21 Update Mouser part numbers / data sheet links.
    [CoPicoVision.kicad_sch, CoPicoVision_audio.kicad_sch, CoPicoVision_controllers.kicad_sch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]
2024-12-21 Replace schematic and board render images.
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2024-12-22 Add / correct a bunch of Mouser part numbers for the BoM.
    [CoPicoVision.kicad_sch, CoPicoVision_audio.kicad_sch, CoPicoVision_controllers.kicad_sch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]
2024-12-22 Update the BoM with corrected part numbers for the caps, add part numbers for a bunch of the jellybean parts.
2024-12-22 Note rev 2.0.1, which contains corrections to the BoM.
2024-12-30 Fix an issue with the memory address decoder for SGM games that disable the BIOS ROM: Use the /RD signal rather than the /WR dignal to distinguish reads vs writes to the first 8KB of the address spac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
    [CoPicoVision.kicad_sch, CoPicoVision_audio.kicad_sch, CoPicoVision_controllers.kicad_sch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]
2024-12-31 Add a simulation for the upcoming AY-3-8910 clock fix interposer board for rev 2.x CoPicoVisions.
2024-12-31 Add an AY-3-8910 interposer board for rev 2.x CoPicoVisions that fixes the AY-3-8910 clock input problem by dividing the clock by 2 with a D-type flip-flop.
    [rev2_x_ay_interposer-B_Cu.gbr, rev2_x_ay_interposer-B_Mask.gbr, rev2_x_ay_interposer-B_Paste.gbr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]
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2025-01-01 Overhaul the clock circuit to use a 14MHz oscillator and counter chip to divide the clock by 4 (CPUCLK) and 8 (AYCLK).
    Welcome to rev 3.0.
    [CoPicoVision.kicad_sch, CoPicoVision_audio.kicad_sch, CoPicoVision_controllers.kicad_sch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]
2025-01-07 Switch to the upstream-issue-28 branch until Troy merges the changes.
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2025-01-24 Change the VGA resistor ladder DAC to surface mount packages.
    [CoPicoVision_video.kicad_sch]
2025-01-24 Update issue date.
    [CoPicoVision.kicad_sch, CoPicoVision_audio.kicad_sch, CoPicoVision_controllers.kicad_sch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]
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2025-02-21 Add an XRAMAD signal that is high **unless** we're accessing the base RAM page with extended RAM disabled. This signal will be used to gate A10-A12 to get the base CV "mirroring" behavior (which curr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
2025-02-21 - If test8 fails, hex dump the test pattern area. - XXX Until the board is re-worked, enable extended RAM while we write the test pattern to the ROM area when the ROM is disabled. If we don't do this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
2025-02-21 Gate A10-A12 of the SRAM using the new XRAMAD signal coming from the MEMDEC GAL, rather than from XRAMEN.
    [CoPicoVision_memory.kicad_sch]
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

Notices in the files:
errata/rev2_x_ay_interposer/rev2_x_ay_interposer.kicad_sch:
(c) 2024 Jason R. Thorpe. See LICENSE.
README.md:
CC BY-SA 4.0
